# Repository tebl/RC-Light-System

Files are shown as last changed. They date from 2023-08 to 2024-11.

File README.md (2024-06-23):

# RC Light System
The *Arduino Starter Kit*, the official one with a bunch of parts and a book, was my first real introduction to working with electronics. Sure, I had put a new power plug on various things as a child of a different time that this one. What I hadn't done, was learn how to not blow things up when trying out new things. Arduino is pretty much perfect for that. Not in that you won't blow things up, it's more a case of blowing up really cheap parts and you rarely, if ever, actually set anything on fire. Working through it all, I wanted to create a project of my own - I would make a better light system for RCs.

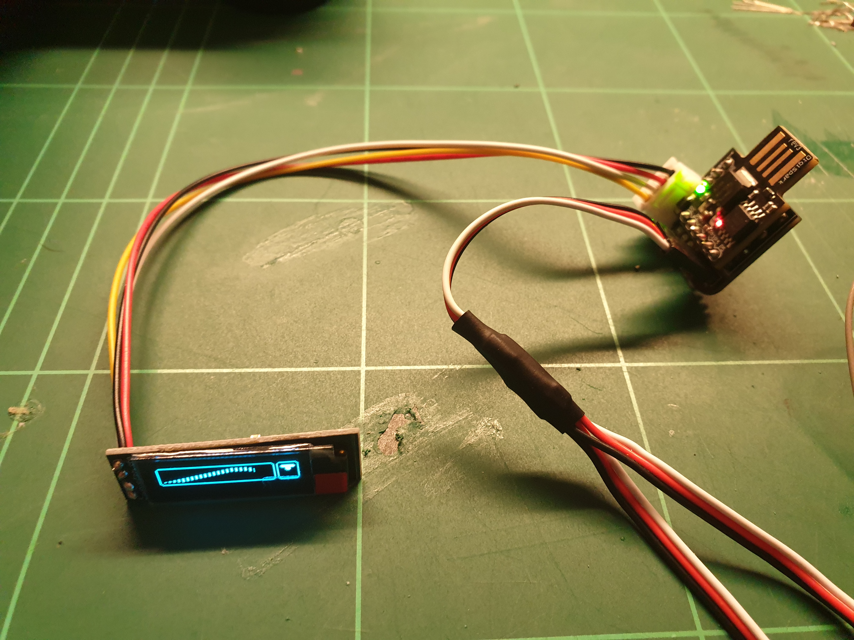
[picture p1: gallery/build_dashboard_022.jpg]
RC Dashboard


Yeah! Turns out that doing exactly that, requires understanding a lot more than simply plugging an LED into a breadboard and turning it on or off - there's logic levels, reading a PWM signal and then figuring out how to design your own PCBs. So I eventually put my parts in the infamous *"someday"* pile. A decade later, I've learned a few things and it was time to take something off that pile and try again! 

As I had a lot of fun doing it, I wanted to build a multitude of slightly different things around the same core theme - RCs, lighting and cool effects. For that reason I found it easier to organize them into their own sub-projects, so follow the links to the ones you are specifically interested in.

- [1> Projects](#1-projects)
  - [1.1> RC Light System](#11-rc-light-system)
  - [1.2> RC Exhaust](#12-rc-exhaust)
  - [1.3> RC Dashboard](#13-rc-dashboard)

# 1> Projects
For the technical details as well as information regarding the projects included in this specific github repository, consult the table below and follow along for the things that may interest you.  As each project will realistically end up being done in several different ways, they will each come with their own set of documentation as well as BOM-listings - these are organized by putting all that into the documentation for each module below it. Organized separately, you are also recommended to check out the [schematics](https://github.com/tebl/RC-Light-System/tree/main/documentation/schematic) for detailed information about how the electrical side of things work.

| Module | Description |
| --- | --- |
| [RC Light System](#11-rc-light-system)  | A functional light system for RCs. It's big, bulky and does mostly what I want it to do.
| [RC Exhaust](#12-rc-exhaust) | Controls an RGB LED mounted inside the exhaust pipe of an RC. On heavy throttle it starts glowing red, ease up on the trottle afterwards and you get flashing colours as it backfires.
| [RC Dashboard](#13-rc-dashboard) | Connected to the receiver, it shows a digital throttle gauge on a small OLED-screen.

## 1.1> RC Light System
This is the project I had originally intended to design, almost a decade earlier. A lighting system with some kind of recognizable intelligence to it. More specifically, something that wouldn't turn on the blinkers when turning the wheel. I could always just cut the wire, but I wanted it to work so that it felt more *scale* - turning on the blinker when cornering around a racetrack at subsonic speeds wasn't it. My second requirement was that it should be detachable by cable, mostly so that the electronics mounted on the chassis could be separated from those that are stuck to the body.

I can't physically work with small components, so as for any practical usage you will need a lot of space to install this - possibly a truck of some kind. Other than that, consider it *educational* material for anyone that wants to connect an Arduino to an RC-receiver.

| Module | Description |
| --- | --- |
| [RC Light System](https://github.com/tebl/RC-Light-System/tree/main/RC%20Light%20System)  | Main module for mounting on chassis, uses Arduino Pro Micro.
| [RC Light System Output](https://github.com/tebl/RC-Light-System/tree/main/RC%20Light%20System%20Output)  | Output-module for mounting on a body. Four sets of two LEDs can be combined to have two levels of brightness.
| [RC Light System Output Mini](https://github.com/tebl/RC-Light-System/tree/main/RC%20Light%20System%20Output%20Mini)  | Output-module for mounting on a body. Slightly smaller than the other one, with almost none of the interesting features apart from turning LEDs on and off.

## 1.2> RC Exhaust
Working with the [RC Light System](#11-rc-light-system), I came across small metal exhaust pipes for 1:10 RCs on AliExpress. Arriving in the mail a couple of months later I knew I had to install them in something, given that they were designed to fit an LED inside it - I wanted something more exciting than a basic effect. I wanted it to glow red on heavy throttle, backfire when easing up on the throttle and so on!

| Module | Description |
| --- | --- |
| [RC Exhaust Digispark](https://github.com/tebl/RC-Light-System/tree/main/RC%20Exhaust%20Digispark)  | Exhaust-module based around Digispark, with capability for RGB colour LED.

## 1.3> RC Dashboard
Tightly related to the [RC Exhaust](#12-rc-exhaust) in terms of implementation, mostly because I initially couldn't get it to work - so in the end I had to put a screen on one, all in order to figure out all the ways it had initially failed to work. That doesn't sound like a fun thing to build, but when doing it I had an idea - why not mount the screen inside the interior of an RC car? Cars generally have those, we call them *"dashboards"*.

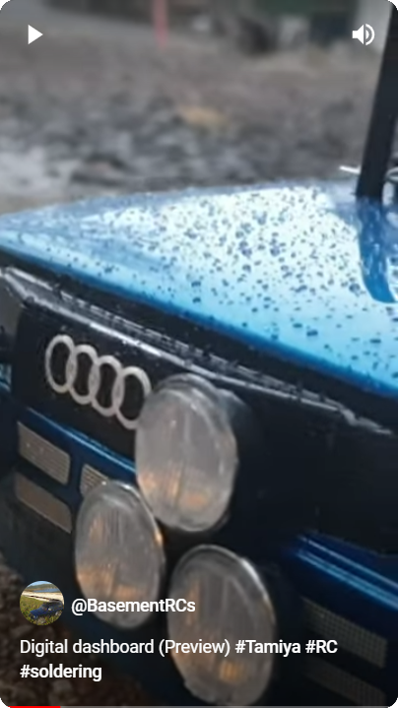
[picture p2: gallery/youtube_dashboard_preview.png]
YouTube image (https://youtube.com/shorts/HmBhJOPVMgE)


An electric RC doesn't exactly have a lot of telemetry that's available to plug into, but at least I can put a throttle gauge on it. Nowadays you'd probably want an analog one, but I designed this one to mimic the digital future that was on display in a limited selection of 80s and 90s cars - check out [The definitive collection of cool 1980s digital dashboards in Euro cars
](https://drivemag.com/red-calipers/the-definitive-collection-of-cool-1980s-digital-dashboards-in-euro-cars/) to see some examples of what I'm talking about here.

| Module | Description |
| --- | --- |
| [RC Dashboard Digispark](https://github.com/tebl/RC-Light-System/tree/main/RC%20Dashboard%20Digispark)  | Dashboard-module based around Digispark.

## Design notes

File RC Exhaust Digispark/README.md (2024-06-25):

# RC Exhaust (Digispark)
Working with the RC Light System, I came across a small metal exhaust pipe for 1:10 RCs on AliExpress. Arriving in the mail a couple of months later, I knew I had to install them in something. Careful measuring revealed that they were designed to fit an LED inside it, and later versions that I picked up even came with one included. I did however want something that was a little more dynamic than a static LED could provide and while I could have gone with the 555, I went the full route of the Attiny85. Granted, I did have some Digispark modules that I'd never found a use for. Until now.

The plan was to have the exhaust pipe glow red on heavy throttle, then backfire when easing up on the throttle. It'll throw in some regular sparks here and there to make it come alive a bit more than that, but the code is included here if you want something else.

- [1> Building the device](#1-building-the-device)
- [2> Schematic](#2-schematic)
- [3> BOM](#3-bom)

# 1> Building the device
Building the device should be a straight-forward affair, you just solder the meager selection of components into place. Pay attention to keep the alignment of the parts somewhat straight, then you should be good. This documentation was written with a board that looks like the following in mind, but note that the github-repository may contain changes that have yet to be tested (therefore, it is recommend that PCBs are ordered using PCBWay links listed in the BOM).

The Attiny85 is a 5v chip, and we're connecting it to a 6v source due to it living inside an RC. Normally that would toast it as we're working outside the acceptable ranges, but we're using a diode with a voltage drop that's up to 0.7v - bringing us withing the tolerances of the chip. As for installation, just match the silver stripe on the component to the stripe part on the board and you're good to go.

Resistors should be added, but you can *probably* skip R4 and R5 - those form a voltage divider in case the receiver is sending out a signal that's above 3.3v. I've not encountered any of those, but then again - I don't have RC equipment older than a decade or so. Link the corresponding *NO_VOL_DIV* pads on the back of it if you've skipped them.

The three at the bottom are for the LEDs, here you may need to match the datasheet for your specific LED, per colour, in order to arrive at a suitable resistor value. Consult a [LED Series Resistor Calculator](https://www.digikey.com/en/resources/conversion-calculators/conversion-calculator-led-series-resistor) if you need to (set supply voltage to 5.3v, fill in 10mA current for blue/green and 15mA for red).

The Digispark itself is then soldered on top, with straight pin headers between the two. It doesn't matter if you used the Digispark shaped like a "USB-key", or if it has a Micro-USB socket on it - they fit just the same. Personally I prefer the former as it is easier to wipe off compared to pulling debris out of a socket.

The LED must be attached to the board using a removable lead, which is why I'm using JST XH plugs on mine. When wiring for an RGB LED it must be a common anode variety, but you can use a normal LED as well - just wire it up to the board as *RED*. If you don't care about being able to reprogram the board later, you can just solder the wires directly. When soldering onto the LED legs, I recommend using heat shrink tubing to avoid any accidents. An easier alternative is to use a pre-wired red LED and just connect up those two leads, but won't look as fancy.

The left hand side is where you connect up the wire coming from the ESC, there are two here - mainly so that you could use it as a Y-lead without requiring any additional cables. Solder wires, or install pin headers depending on what you prefer.

# 2> Schematic
The supplied KiCad files should be sufficient as both a schematic and as a  starting point for ordering PCBs (basically you could just zip the contents of the export folder and upload that on a fabrication site), the schematic is also available in [PDF-format](https://github.com/tebl/RC-Light-System/tree/main/documentation/schematic) and this is what you'll need to print and work your way through when things fail to work as expected.

# 3> BOM
Most parts should be easy to get a hold of from your favourite local electronic component shop, but given that I don't have access to such shops where I live so everything was based on whatever I could get cheapest from eBay/AliExpress (free shipping, but plan on waiting 3-4 weeks for delivery). As I expect that most will build this adapter solely for MIDI-output, the values required for the MIDI input have been listed in parenthesis.

| Reference | Item | Count | Order  |
| ---| --- | ----- | --- |
| Faceplate PCB  | Fabricate using Gerber files | 1 | PCBWay
| A1 | Digispark-module (with pin-headers) | 1 |
| D1 * | 4-pin JST-XH socket | 1 |
| | 5mm LED, common-anode variety to 4-pin JST-XH plug | 1 |
| D2 | 1N4001 diode (DO-41) | 1 |
| J5,J6 | Straight pin-headers, alternatively wire a Y-splitter | 1 |
| R1 | 200 ohm resistor | 1 |
| R2,R3 | 270 ohm resistor | 2 |
| R4 | 10k ohm resistor | (1)|
| R5 | 20k ohm resistor | (1)|

*) You can come up with something else here, but JST-XH is what I recommend. They're keyed and locking so they won't come off very easily. For the LED, I recommend buying pre-wired 4-pin JST-XH leads with plugs already on it - you'll need to solder it to the individual LED legs though (use heat shrink tubing).

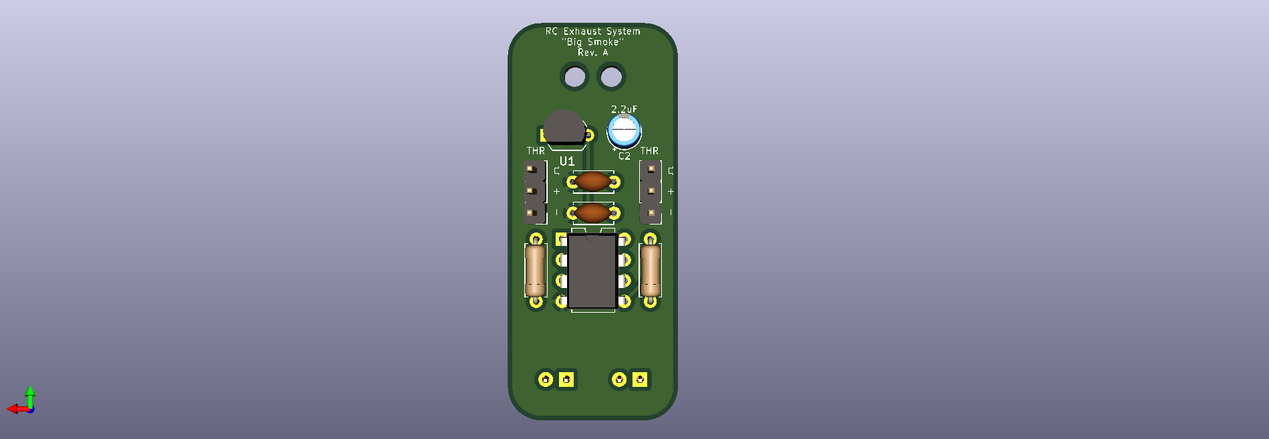
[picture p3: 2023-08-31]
gallery/RC Exhaust System (Top).png

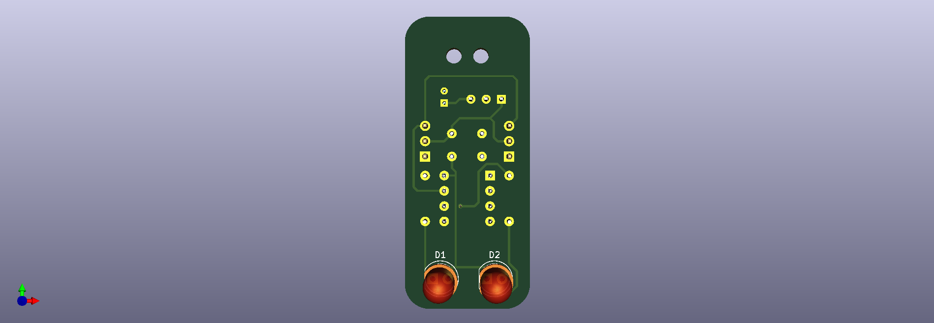
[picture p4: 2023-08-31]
gallery/RC Exhaust System (Bottom).png

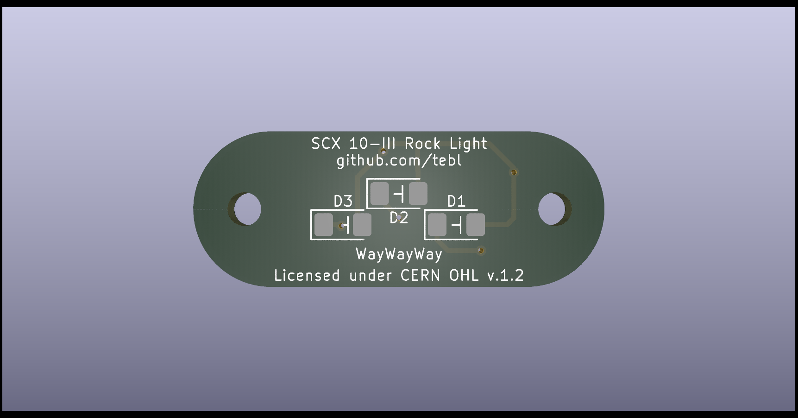
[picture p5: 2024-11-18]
gallery/RC SCX10.3 Rock Light (Bottom).png

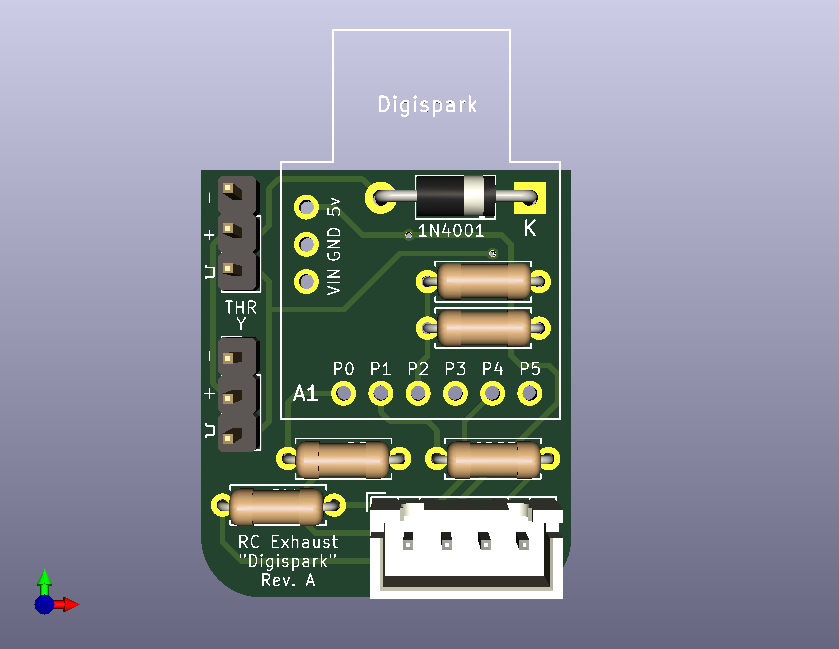
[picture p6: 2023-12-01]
gallery/RC Exhaust Digispark.png

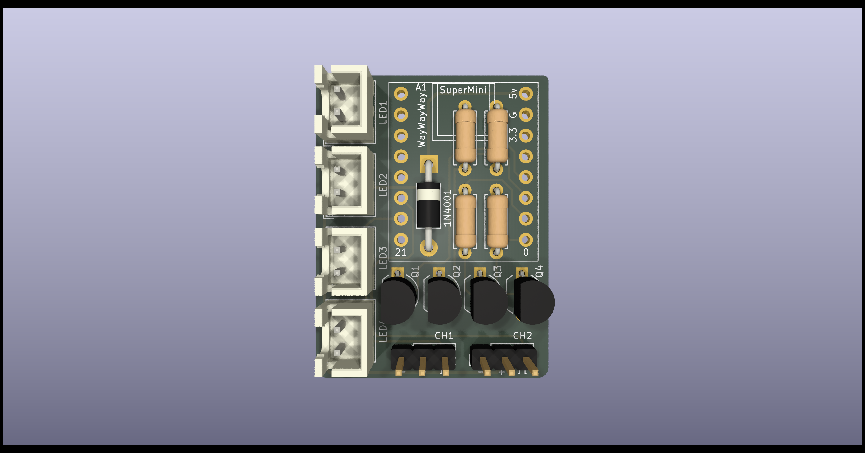
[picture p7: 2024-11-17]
gallery/RC SCX10.3 Rock Control.png

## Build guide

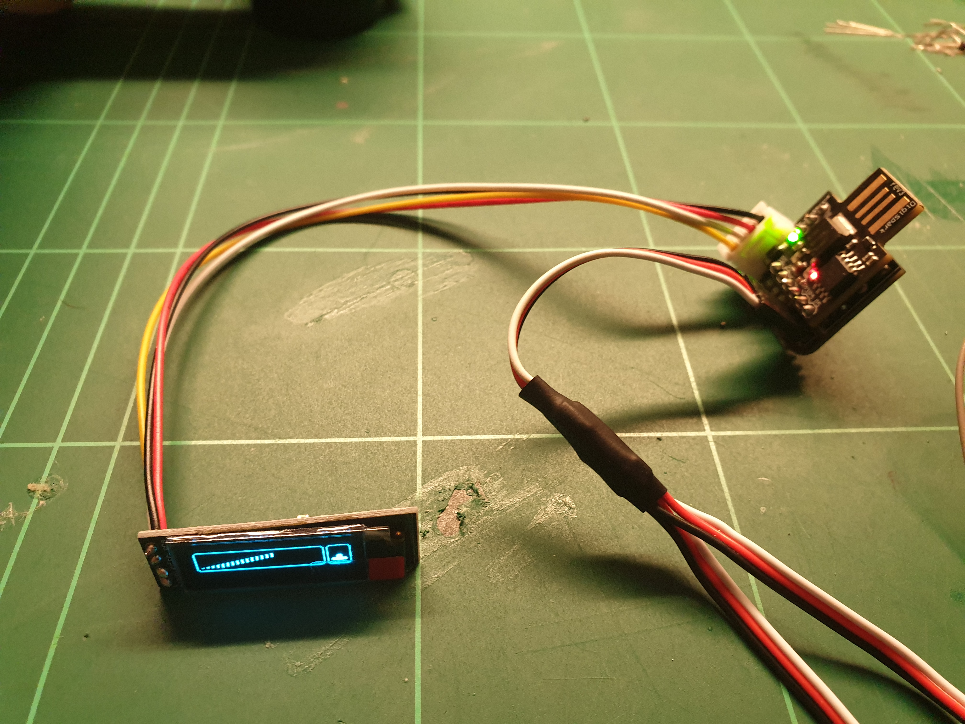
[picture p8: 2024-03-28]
gallery/build_dashboard_023.jpg

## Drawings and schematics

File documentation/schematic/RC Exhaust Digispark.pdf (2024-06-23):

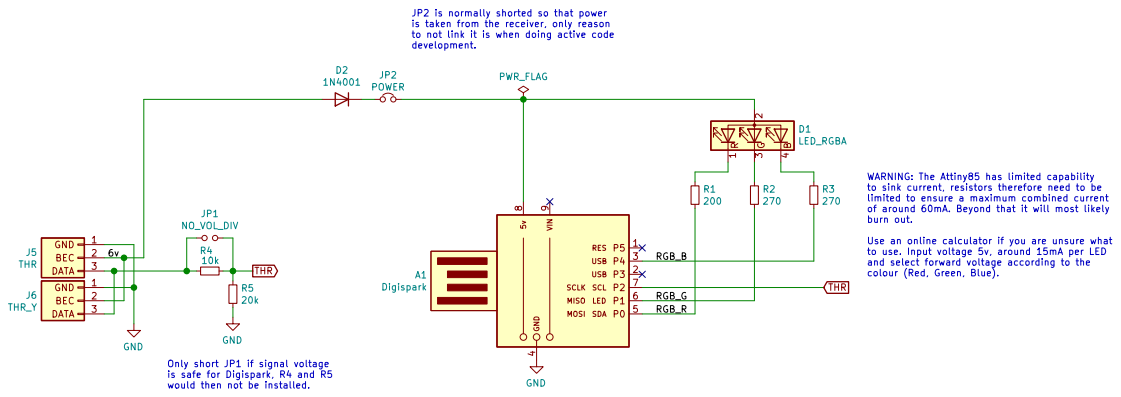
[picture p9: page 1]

JP2 is normally shorted so that power
is taken from the receiver, only reason
to not link it is when doing active code
development.

to sink current, resistors therefore need to be
limited to ensure a maximum combined current of around 60mA. Beyond that it will most likely burn out. Use an online calculator if you are unsure what

SCLK SCL SDA USB USB VIN

RGB_B Only short JP1 if signal voltage

to use. Input voltage 5v, around 15mA per LED
and select forward voltage according to the
colour (Red, Green, Blue).

Found some exhaust tubes for a 1:10 model on AliExpress, let's add some glow effects to BEC

File: RC Exhaust Digispark.sch Sheet: /
Id: 1/1 Title: RC Exhaust Digispark

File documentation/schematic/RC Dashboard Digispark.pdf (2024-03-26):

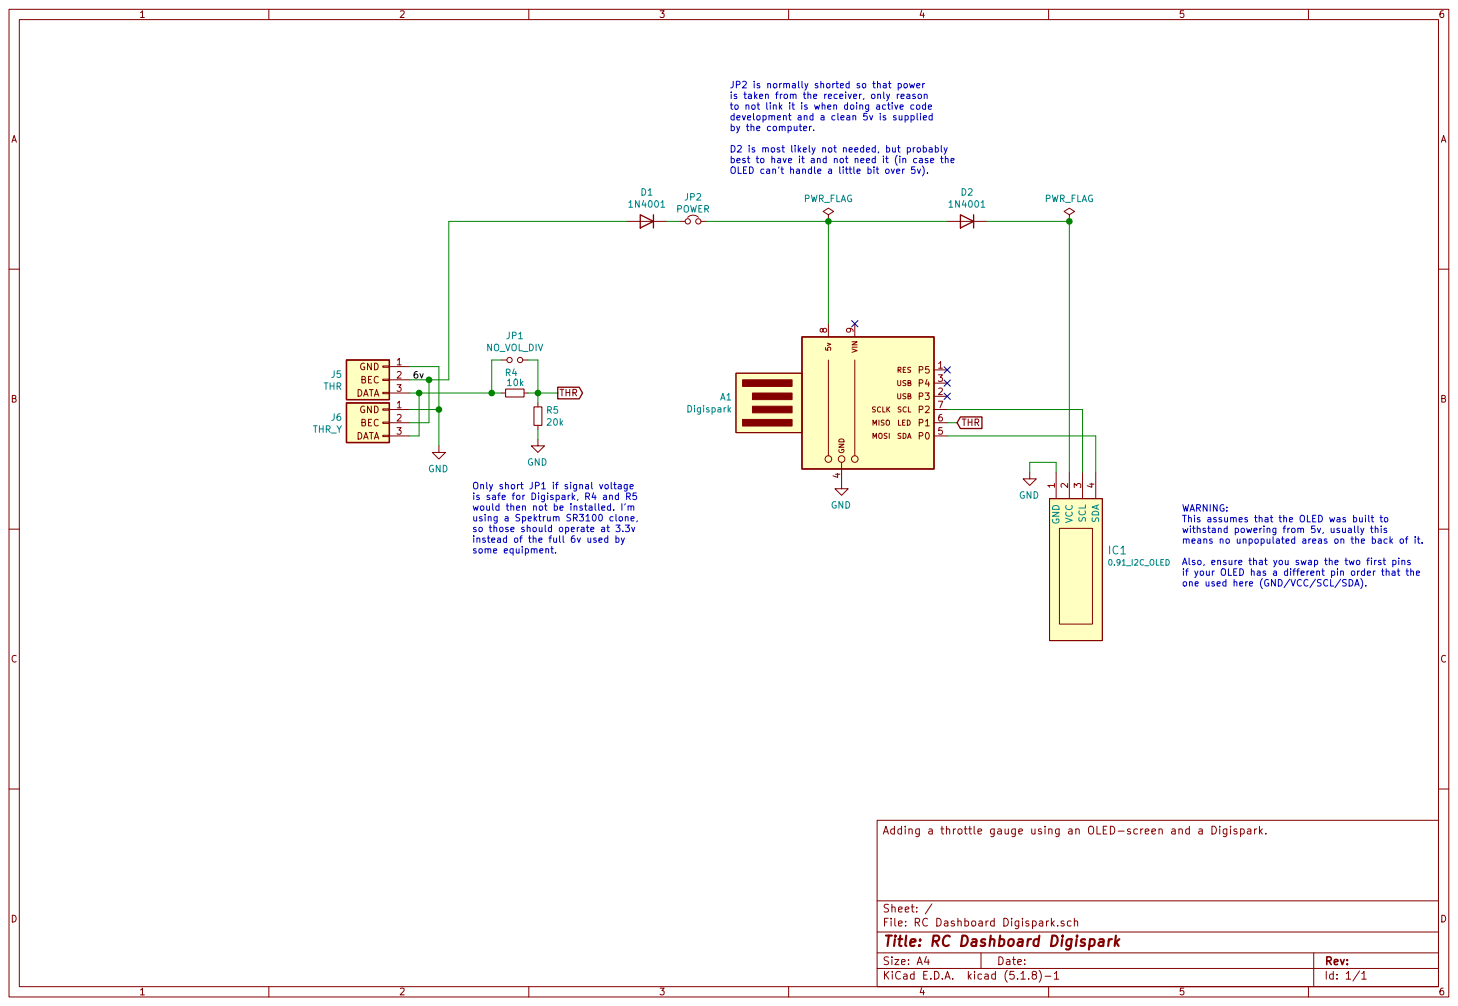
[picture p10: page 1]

JP2 is normally shorted so that power
is taken from the receiver, only reason
to not link it is when doing active code
development and a clean 5v is supplied
by the computer.

D2 is most likely not needed, but probably
best to have it and not need it (in case the

SCLK SCL SDA USB USB VIN

File: RC Dashboard Digispark.sch Sheet: / Adding a throttle gauge using an OLED-screen and a Digispark. BEC

Only short JP1 if signal voltage
is safe for Digispark, R4 and R5 would then not be installed. I'm

using a Spektrum SR3100 clone,
so those should operate at 3.3v
instead of the full 6v used by
some equipment.

means no unpopulated areas on the back of it.

Also, ensure that you swap the two first pins
if your OLED has a different pin order that the
one used here (GND/VCC/SCL/SDA).

Id: 1/1 Title: RC Dashboard Digispark

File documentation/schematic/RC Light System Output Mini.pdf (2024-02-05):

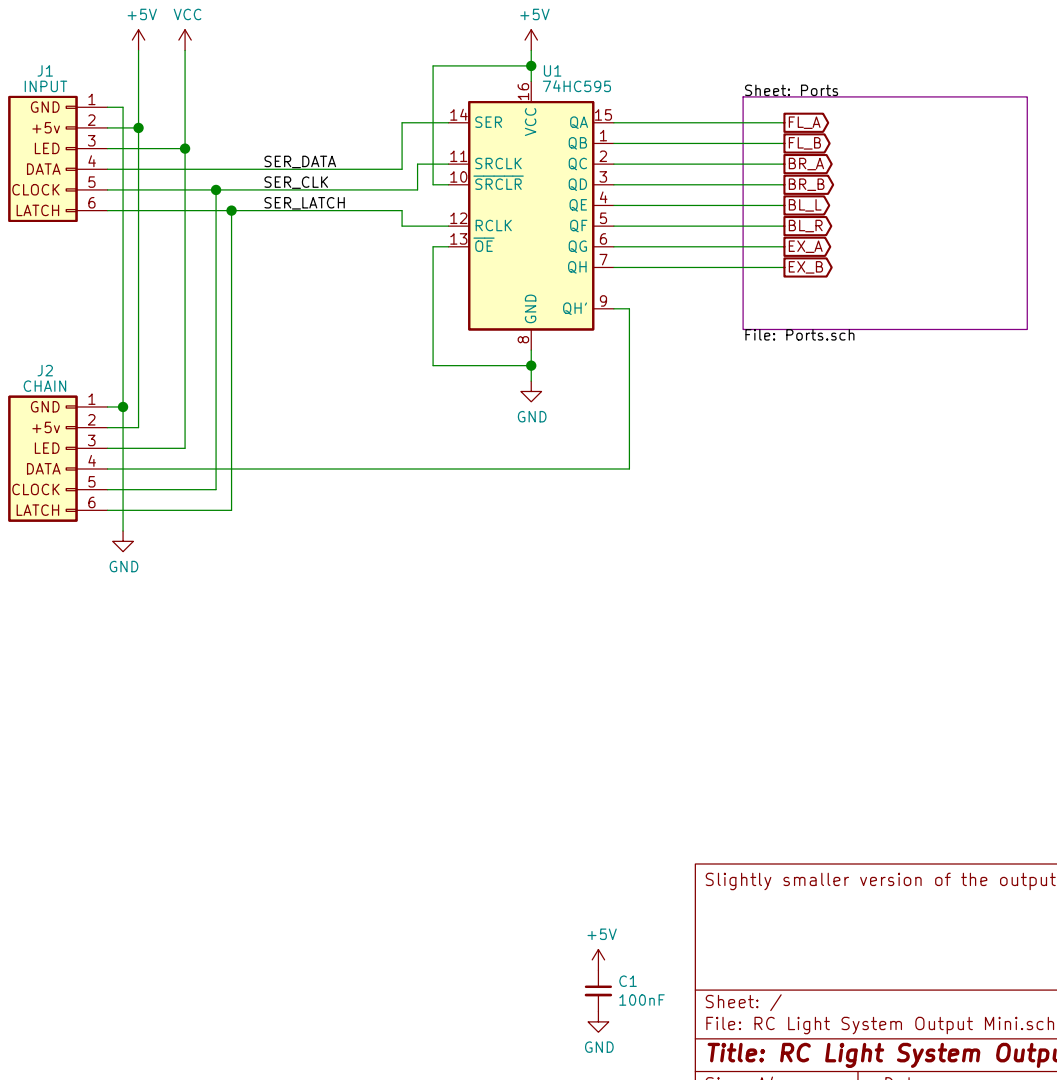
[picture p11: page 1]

Sheet: Ports File: Ports.sch +5V C1

5 | SER_CLK
6 | | SER_LATCH

File: RC Light System Output Mini.sch Sheet: / Slightly smaller version of the output module, gone are most of the interesting features.

Id: 1/2 Title: RC Light System Output (Mini)

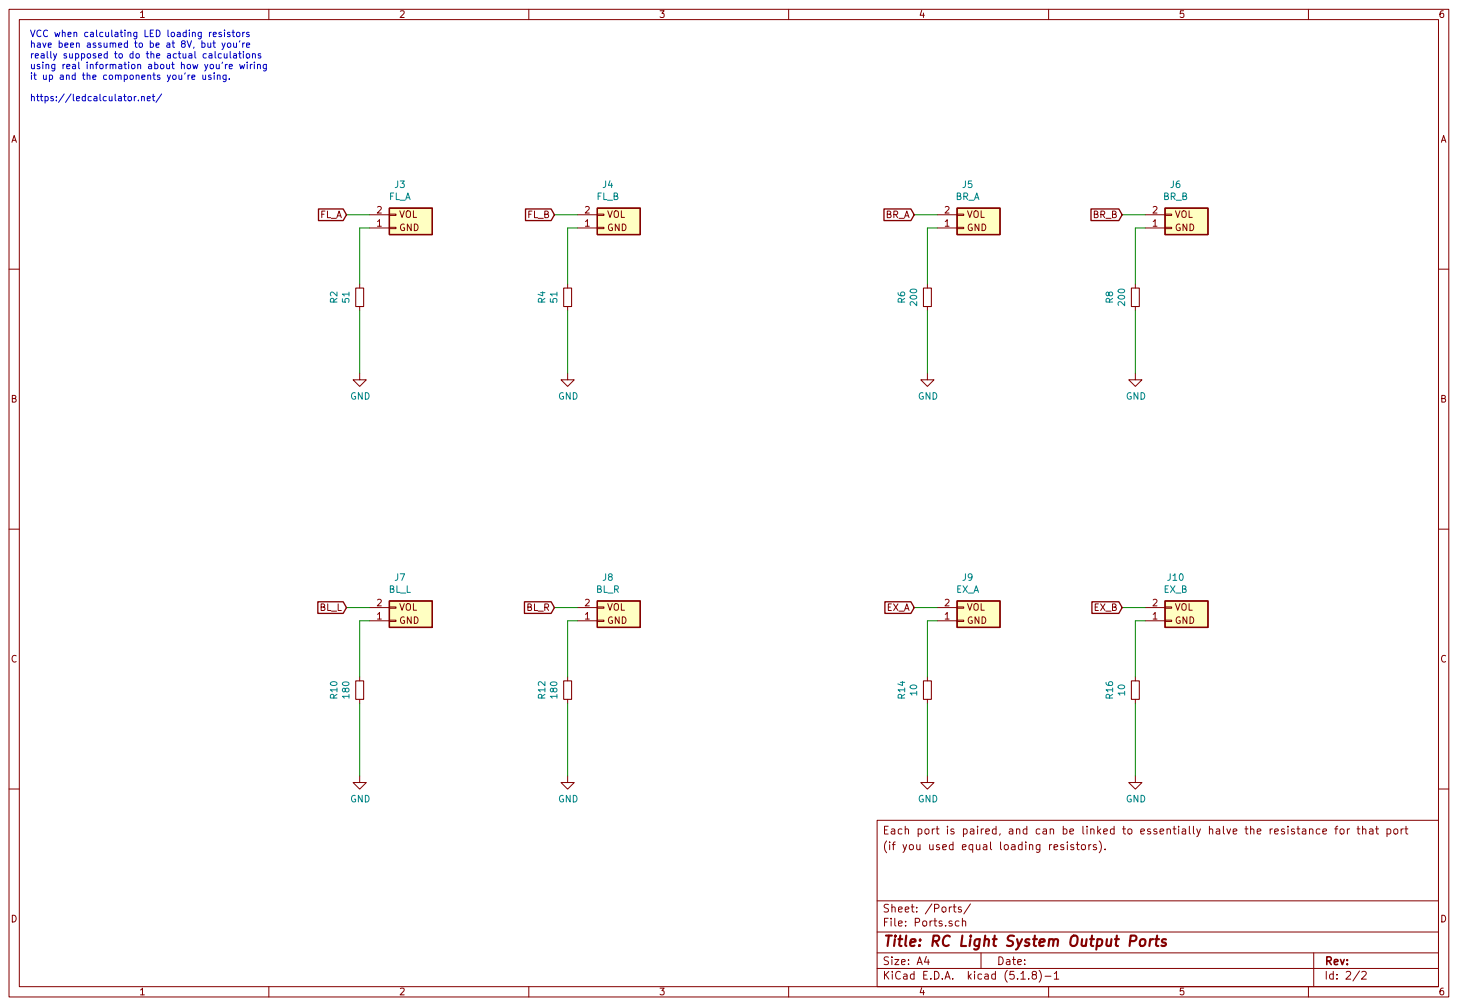
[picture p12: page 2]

VCC when calculating LED loading resistors
have been assumed to be at 8V, but you're
really supposed to do the actual calculations
using real information about how you're wiring
it up and the components you're using.

File: Ports.sch Sheet: /Ports/ (if you used equal loading resistors).

Id: 2/2 Title: RC Light System Output Ports

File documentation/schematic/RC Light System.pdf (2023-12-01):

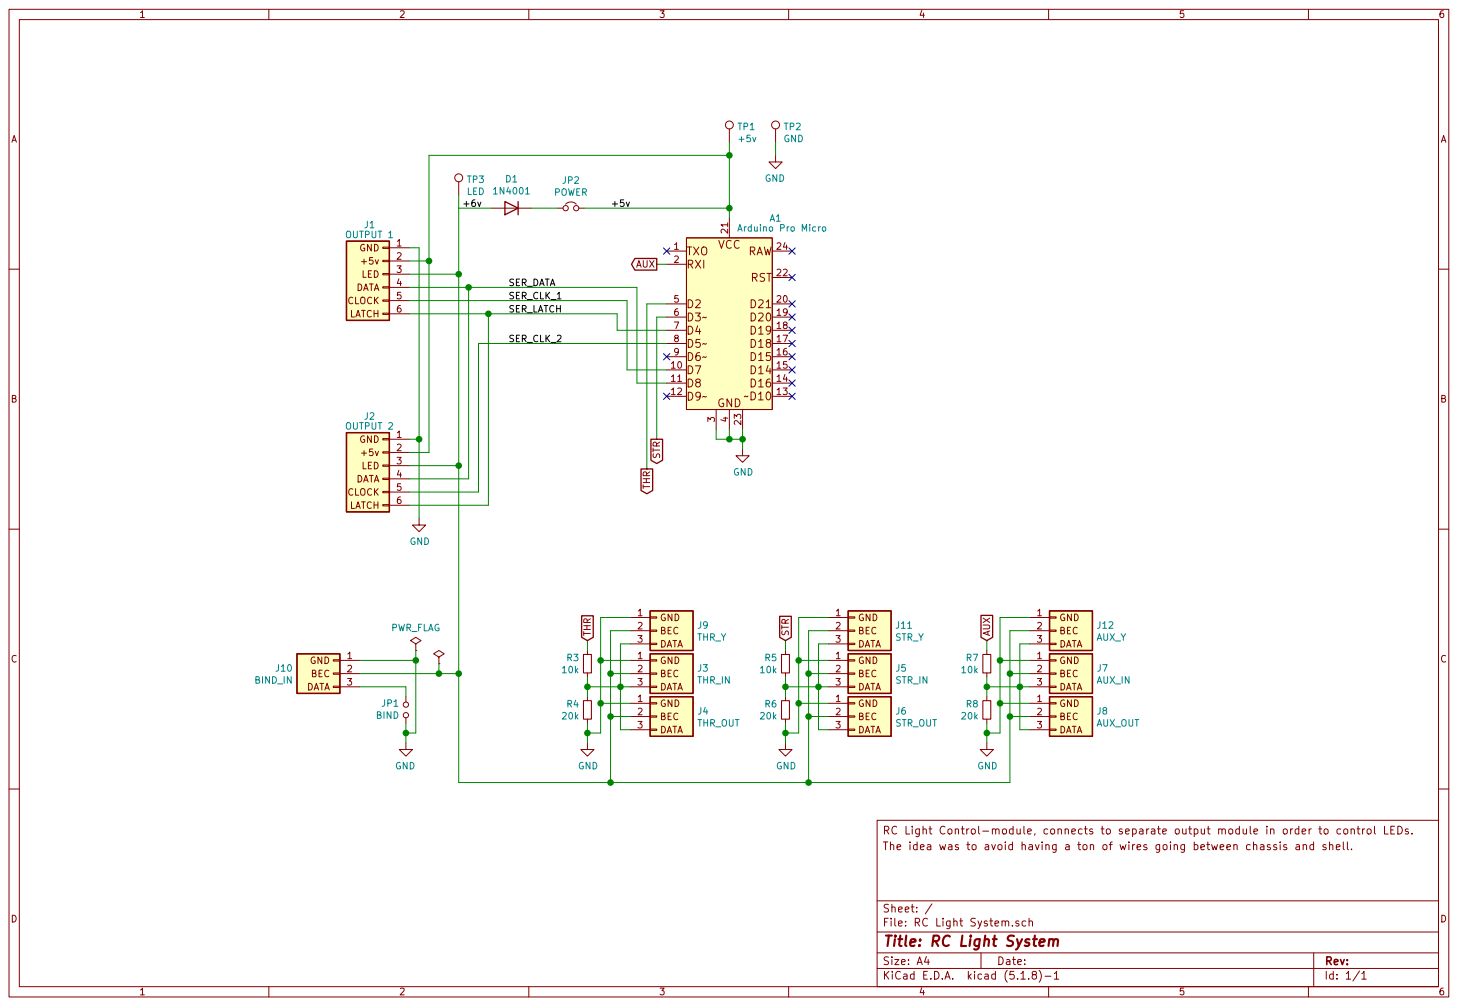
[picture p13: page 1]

10
11

RC Light Control-module, connects to separate output module in order to control LEDs.
File: RC Light System.sch Sheet: / The idea was to avoid having a ton of wires going between chassis and shell.

Id: 1/1 Title: RC Light System

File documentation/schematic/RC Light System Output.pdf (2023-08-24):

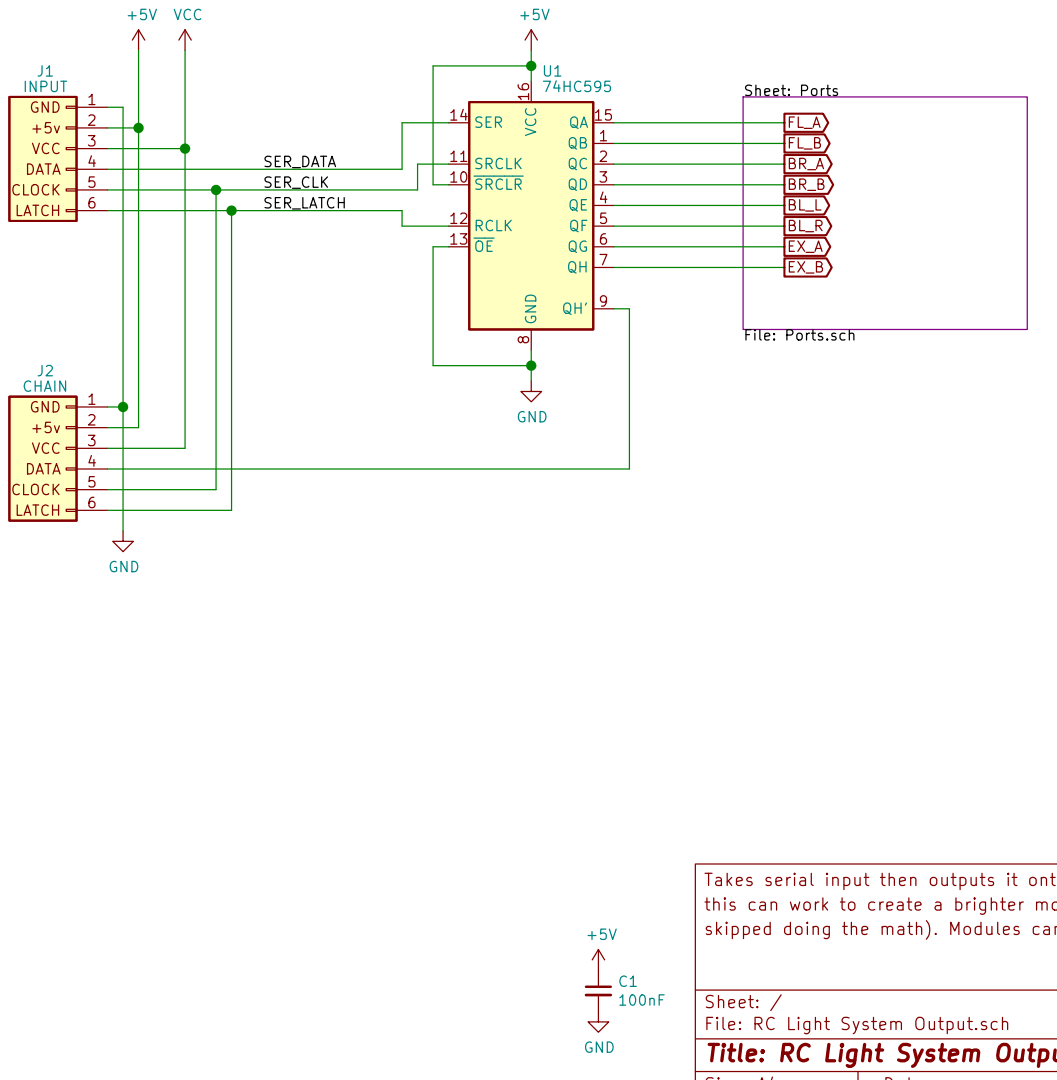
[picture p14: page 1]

Sheet: Ports File: Ports.sch +5V C1

5 | SER_CLK
6 | | SER_LATCH

Takes serial input then outputs it onto LED "ports". Each port is paired and can be linked,
this can work to create a brighter mode for the LEDs connected (or burn something if you
File: RC Light System Output.sch Sheet: / skipped doing the math). Modules can be chained for more outputs.

Id: 1/2 Title: RC Light System Output

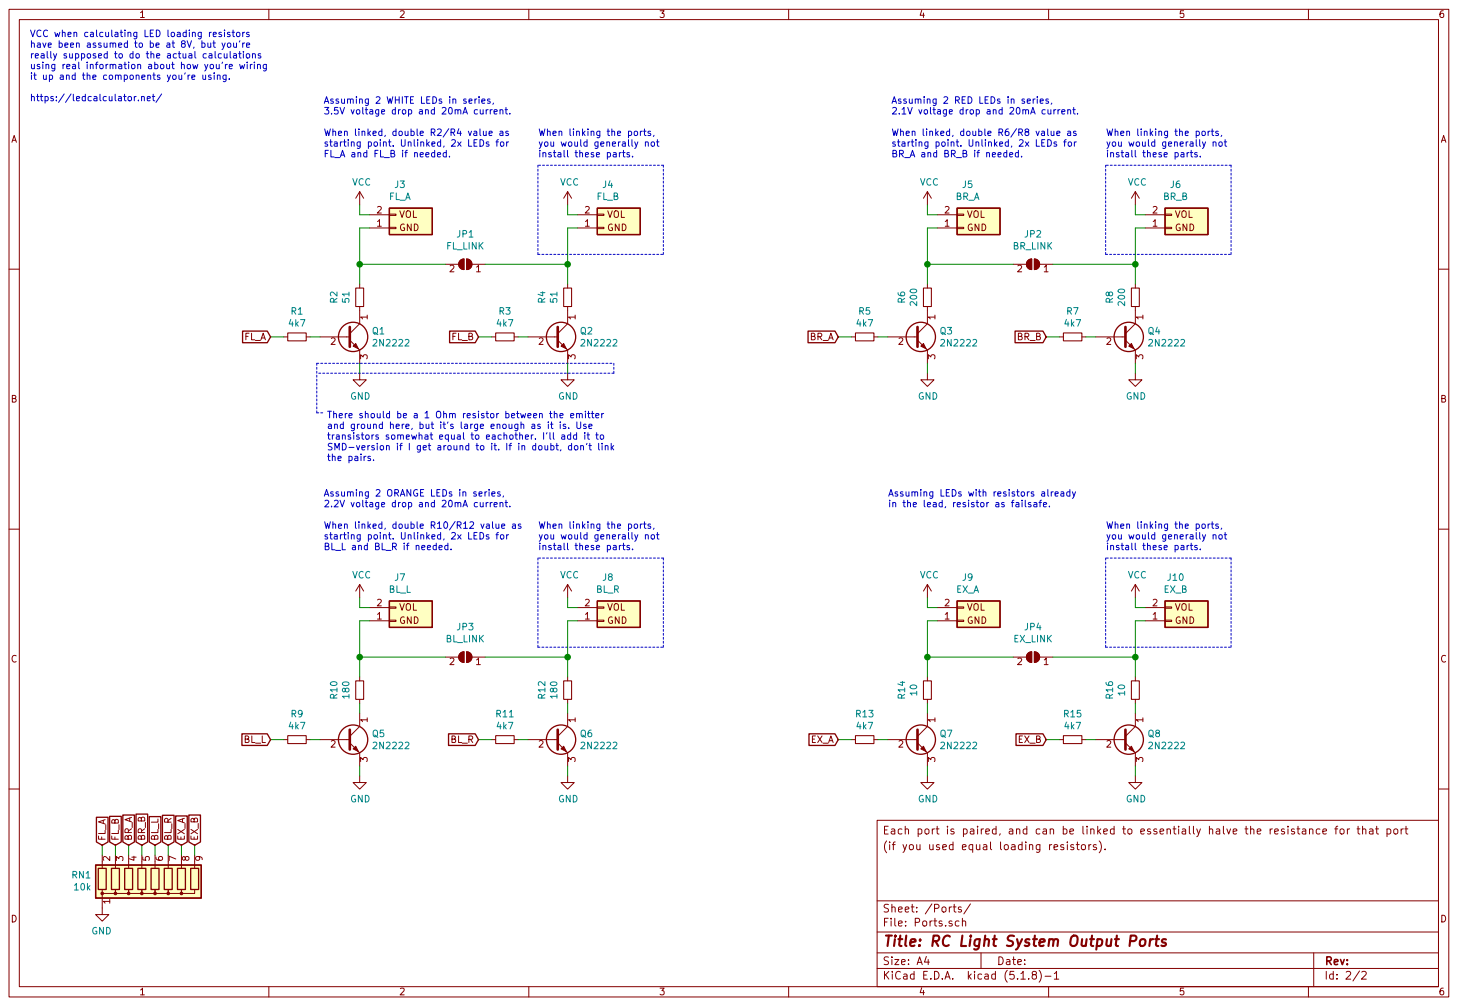
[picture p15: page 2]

VCC when calculating LED loading resistors
have been assumed to be at 8V, but you're
really supposed to do the actual calculations
using real information about how you're wiring
it up and the components you're using.

starting point. Unlinked, 2x LEDs for FL_A and FL_B if needed. Assuming 2 WHITE LEDs in series,
3.5V voltage drop and 20mA current.
VCC R16 10 R6 200 VCC GND

starting point. Unlinked, 2x LEDs for BR_A and BR_B if needed. Assuming 2 RED LEDs in series,
2.1V voltage drop and 20mA current.

install these parts. When linked, double R2/R4 value as

in the lead, resistor as failsafe. When linking the ports,
you would generally not

When linking the ports,

install these parts. When linked, double R10/R12 value as
J7 BL_LVOL GND 1

There should be a 1 Ohm resistor between the emitter and ground here, but it's large enough as it is. Use

transistors somewhat equal to eachother. I'll add it to
SMD-version if I get around to it. If in doubt, don't link
the pairs.

starting point. Unlinked, 2x LEDs for BL_L and BL_R if needed. Assuming 2 ORANGE LEDs in series,
2.2V voltage drop and 20mA current.

Assuming LEDs with resistors already

VCC R12 180

install these parts.

Each port is paired, and can be linked to essentially halve the resistance for that port
File: Ports.sch Sheet: /Ports/ (if you used equal loading resistors).

Id: 2/2 Title: RC Light System Output Ports

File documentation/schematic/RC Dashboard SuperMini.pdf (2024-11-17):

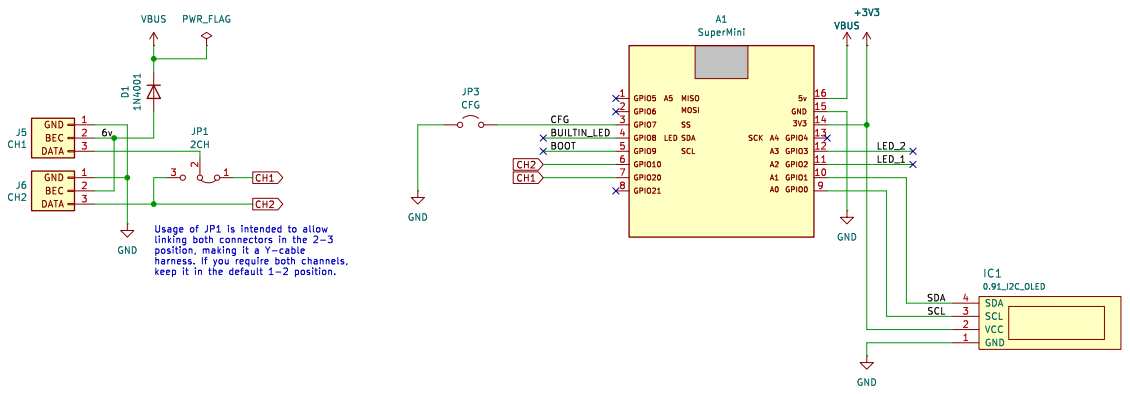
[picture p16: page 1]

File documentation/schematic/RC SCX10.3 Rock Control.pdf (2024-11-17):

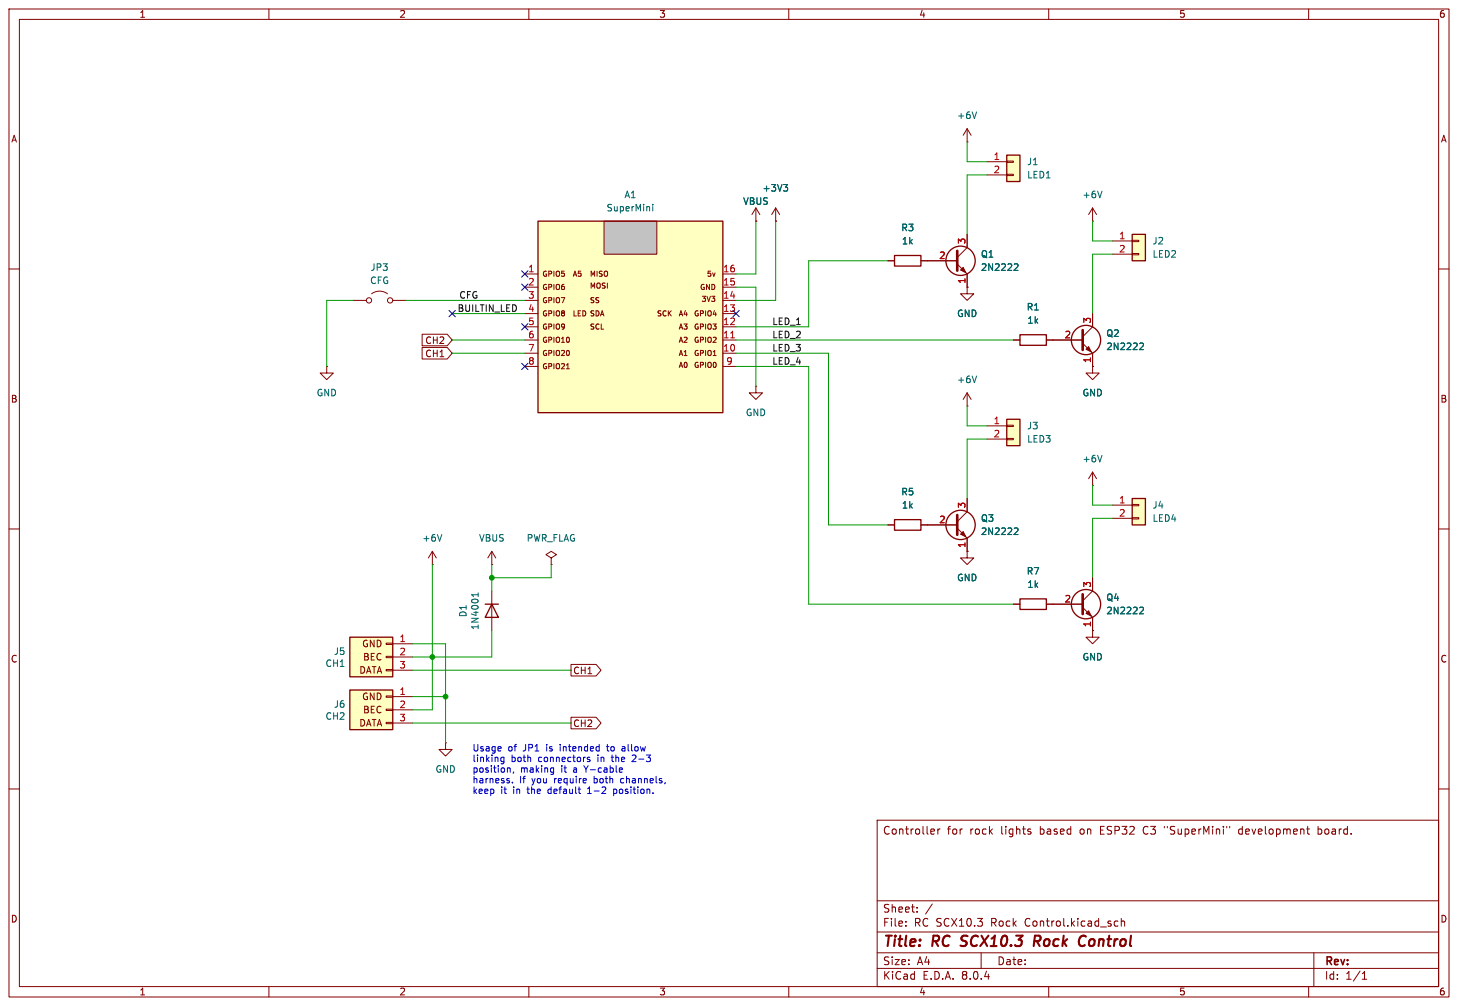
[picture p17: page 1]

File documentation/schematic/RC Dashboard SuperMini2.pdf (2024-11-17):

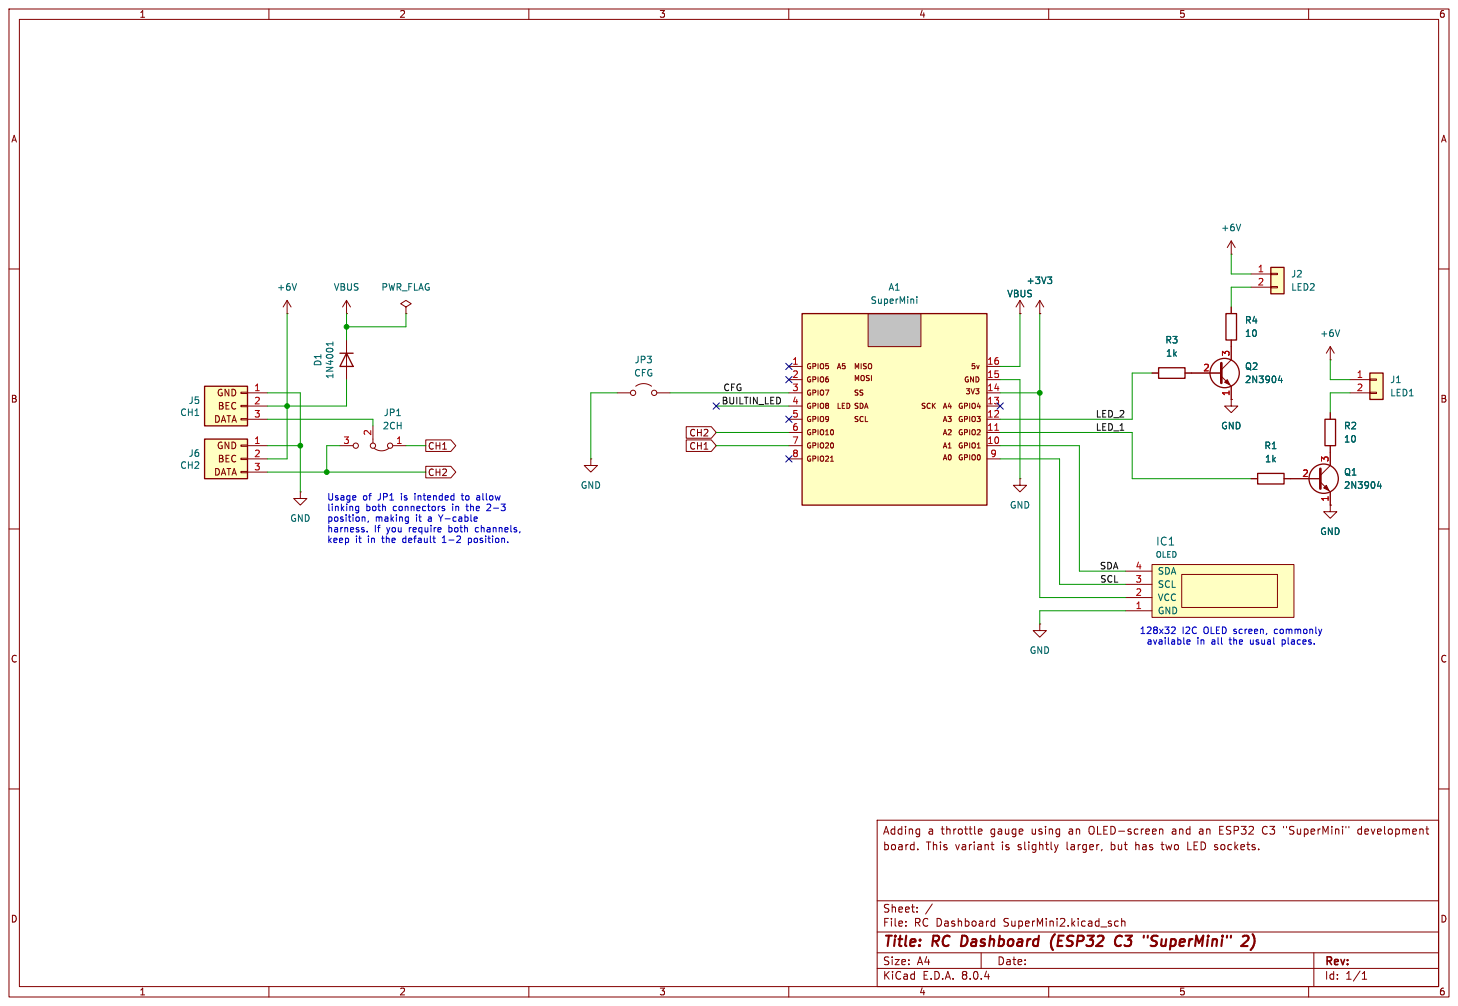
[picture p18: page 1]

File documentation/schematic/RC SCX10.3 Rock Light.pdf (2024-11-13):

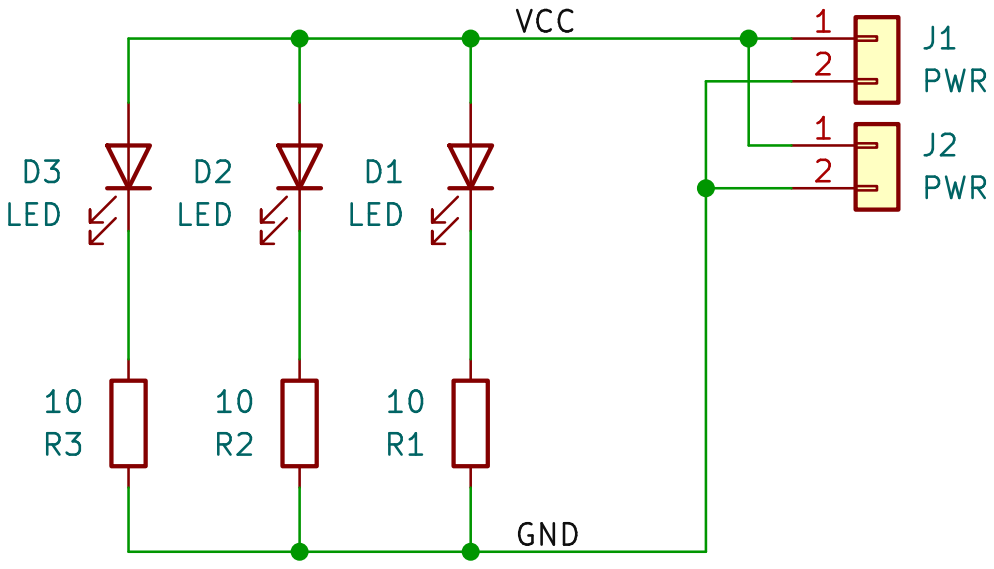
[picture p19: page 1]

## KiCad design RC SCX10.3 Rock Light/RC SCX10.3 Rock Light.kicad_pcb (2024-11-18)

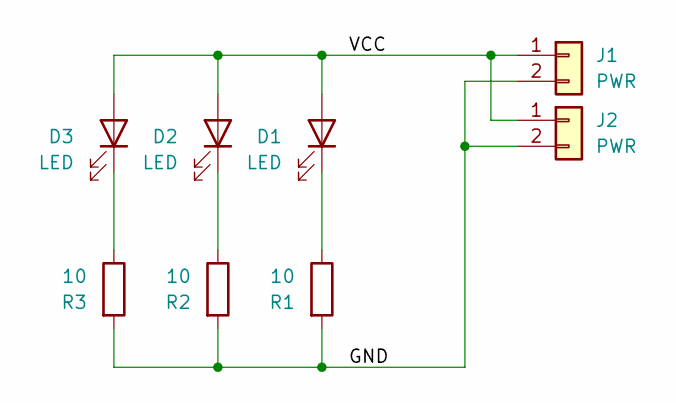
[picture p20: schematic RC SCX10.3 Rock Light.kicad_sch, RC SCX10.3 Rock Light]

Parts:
D1, D2, D3: LED; LED_1206_3216Metric_Pad1.42x1.75mm_HandSolder
J1, J2: PWR; edge_pins_1x02
R1, R2, R3: 10; R_1206_3216Metric_Pad1.30x1.75mm_HandSolder

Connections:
/GND: J1.2, J2.2, R1.2, R2.2, R3.2
/VCC: D1.2 (A), D2.2 (A), D3.2 (A), J1.1, J2.1
unnamed: D1.1 (K), R1.1
unnamed: D2.1 (K), R2.1
unnamed: D3.1 (K), R3.1

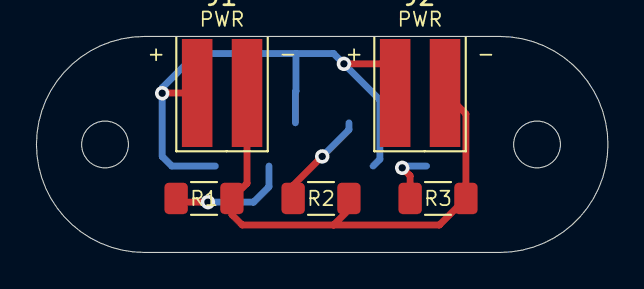
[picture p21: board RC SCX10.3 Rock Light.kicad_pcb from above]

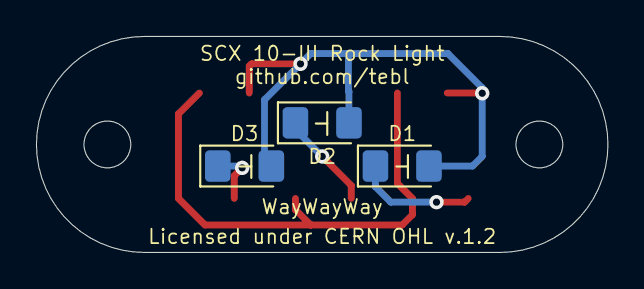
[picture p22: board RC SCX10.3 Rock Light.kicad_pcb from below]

Board: 2 copper layers, 31.8 x 12.0 mm, 8 parts (3 on the bottom side), 5 nets.

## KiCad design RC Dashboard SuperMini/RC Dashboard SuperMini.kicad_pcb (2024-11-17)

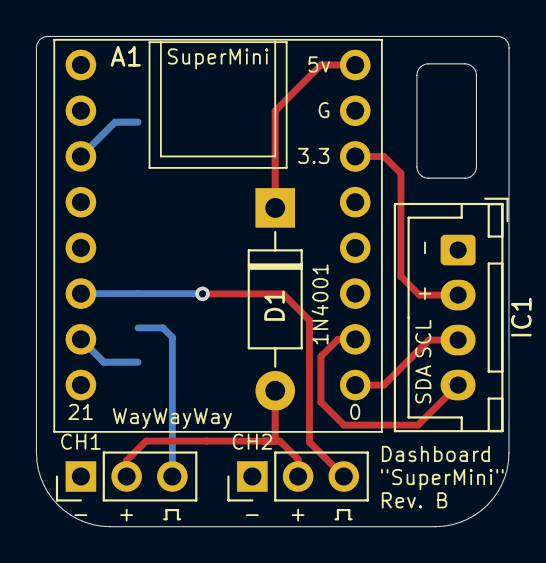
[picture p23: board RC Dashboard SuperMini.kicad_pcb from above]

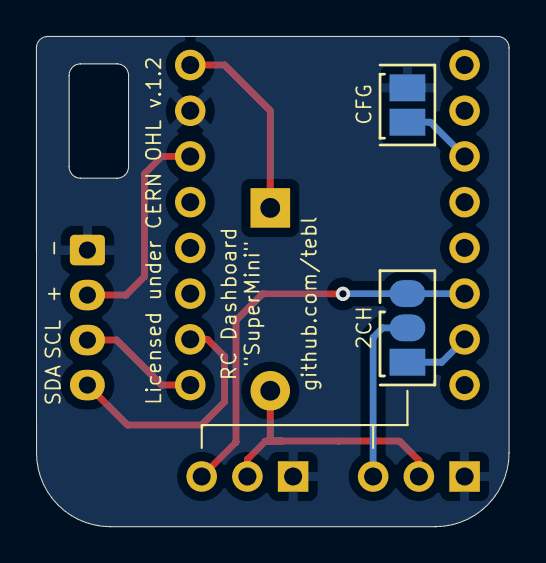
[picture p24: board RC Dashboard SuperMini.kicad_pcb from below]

Board: 2 copper layers, 26.3 x 27.2 mm, 7 parts (2 on the bottom side), 10 nets.

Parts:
A1: SuperMini; SuperMini_ESP32_C3
D1: 1N4001; D_DO-41_SOD81_P10.16mm_Horizontal
IC1: 0.91_I2C_OLED; JST_XH_B4B-XH-A_1x04_P2.50mm_Vertical
J5: CH1; PinHeader_1x03_P2.54mm_Vertical
J6: CH2; PinHeader_1x03_P2.54mm_Vertical
JP1: 2CH; select2
JP3: CFG; bridge

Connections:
+3V3: A1.14 (3V3), IC1.2 (VCC)
/6v: D1.2 (A), J5.2 (BEC), J6.2 (BEC)
/CFG_2: A1.3 (GPIO7), JP3.2 (B)
/SCL: A1.9 (GPIO0), IC1.3 (SCL)
/SDA: A1.10 (GPIO1), IC1.4 (SDA)
CH1: A1.7 (GPIO20), JP1.1 (A)
CH2: A1.6 (GPIO10), J6.3 (VCC), JP1.3 (B)
GND: A1.15 (GND), IC1.1 (GND), J5.1 (GND), J6.1 (GND), JP3.1 (A)
unnamed: J5.3 (VCC), JP1.2 (C)
VBUS: A1.16 (5v), D1.1 (K)

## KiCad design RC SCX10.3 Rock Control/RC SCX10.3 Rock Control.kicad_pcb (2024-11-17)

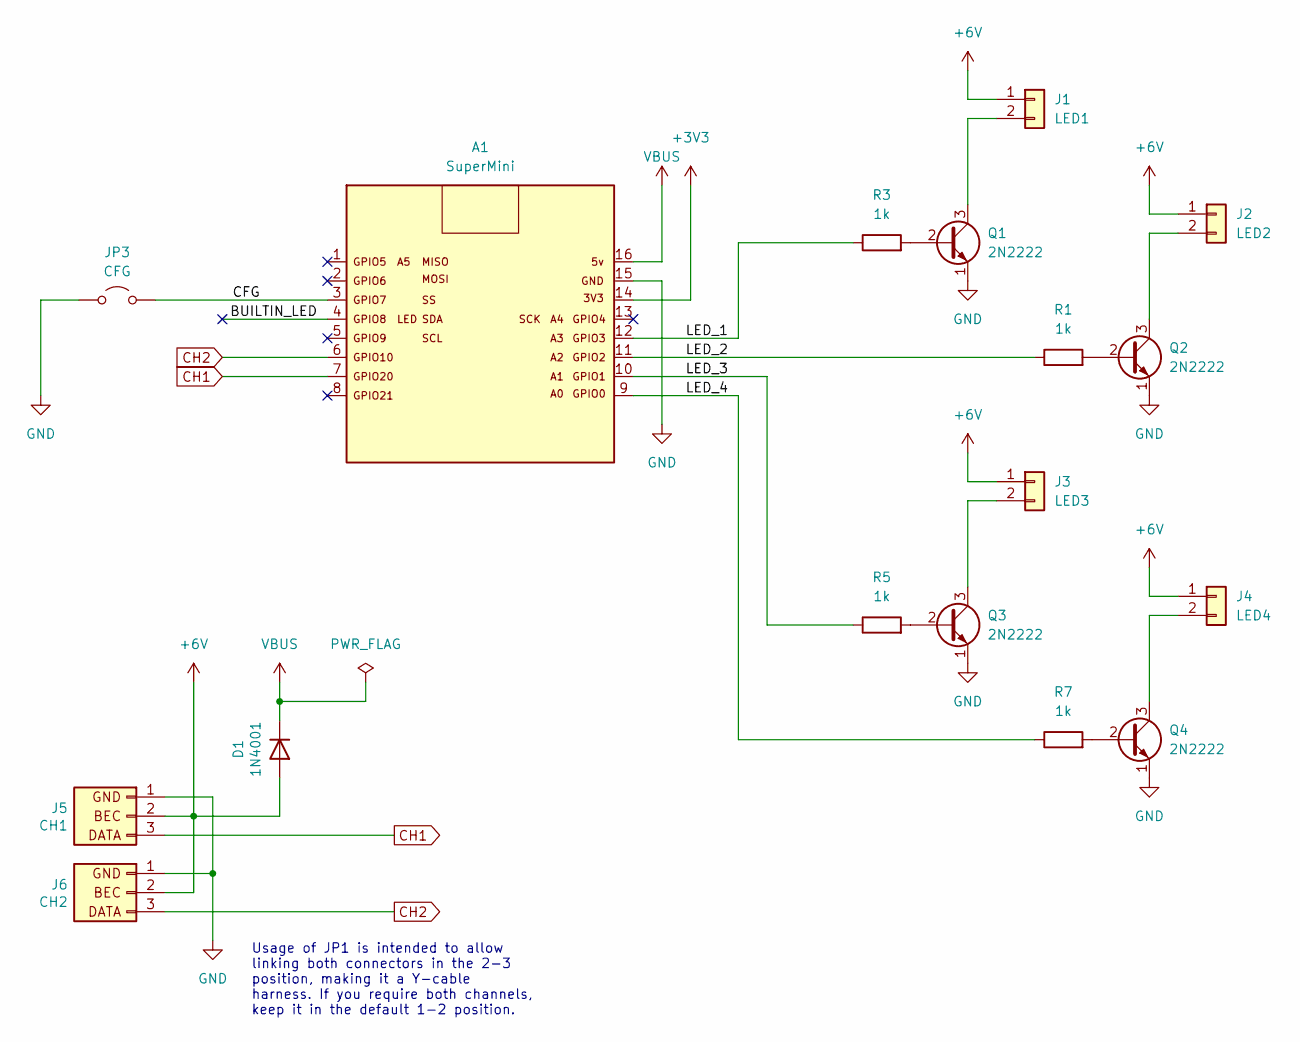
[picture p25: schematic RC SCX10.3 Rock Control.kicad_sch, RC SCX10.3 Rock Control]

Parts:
A1: SuperMini; SuperMini_ESP32_C3
D1: 1N4001; D_DO-41_SOD81_P10.16mm_Horizontal
J1: LED1; JST_XH_B2B-XH-A_1x02_P2.50mm_Vertical
J2: LED2; JST_XH_B2B-XH-A_1x02_P2.50mm_Vertical
J3: LED3; JST_XH_B2B-XH-A_1x02_P2.50mm_Vertical
J4: LED4; JST_XH_B2B-XH-A_1x02_P2.50mm_Vertical
J5: CH1; PinHeader_1x03_P2.54mm_Vertical
J6: CH2; PinHeader_1x03_P2.54mm_Vertical
JP3: CFG; bridge
Q1, Q2, Q3, Q4: 2N2222; TO-92_Inline_Wide
R1, R3, R5, R7: 1k; R_Axial_DIN0207_L6.3mm_D2.5mm_P7.62mm_Horizontal

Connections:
+3V3: A1.14 (3V3)
+6V: D1.2 (A), J1.1, J2.1, J3.1, J4.1, J5.2 (BEC), J6.2 (BEC)
/BUILTIN_LED: A1.4 (GPIO8)
/CFG: A1.3 (GPIO7), JP3.2 (B)
/LED_1: A1.12 (GPIO3), R3.1
/LED_2: A1.11 (GPIO2), R1.1
/LED_3: A1.10 (GPIO1), R5.1
/LED_4: A1.9 (GPIO0), R7.1
CH1: A1.7 (GPIO20), J5.3 (VCC)
CH2: A1.6 (GPIO10), J6.3 (VCC)
GND: A1.15 (GND), J5.1 (GND), J6.1 (GND), JP3.1 (A), Q1.1 (E), Q2.1 (E), Q3.1 (E), Q4.1 (E)
unnamed: J1.2, Q1.3 (C)
unnamed: J2.2, Q2.3 (C)
unnamed: J3.2, Q3.3 (C)
unnamed: J4.2, Q4.3 (C)
unnamed: Q1.2 (B), R3.2
unnamed: Q2.2 (B), R1.2
unnamed: Q3.2 (B), R5.2
unnamed: Q4.2 (B), R7.2
VBUS: A1.16 (5v), D1.1 (K)

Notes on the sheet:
Usage of JP1 is intended to allow linking both connectors in the 2-3 position, making it a Y-cable harness. If you require both channels, keep it in the default 1-2 position.

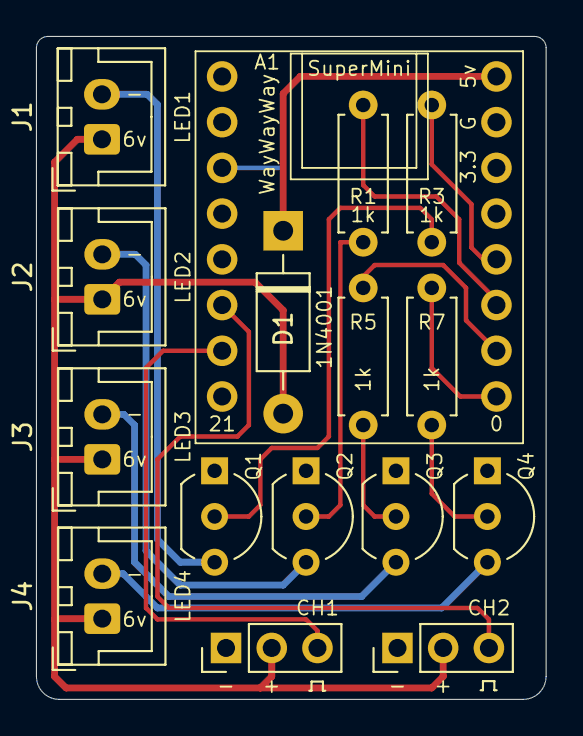
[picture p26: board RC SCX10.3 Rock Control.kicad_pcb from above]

Board: 2 copper layers, 28.3 x 36.8 mm, 17 parts (1 on the bottom side), 18 nets.

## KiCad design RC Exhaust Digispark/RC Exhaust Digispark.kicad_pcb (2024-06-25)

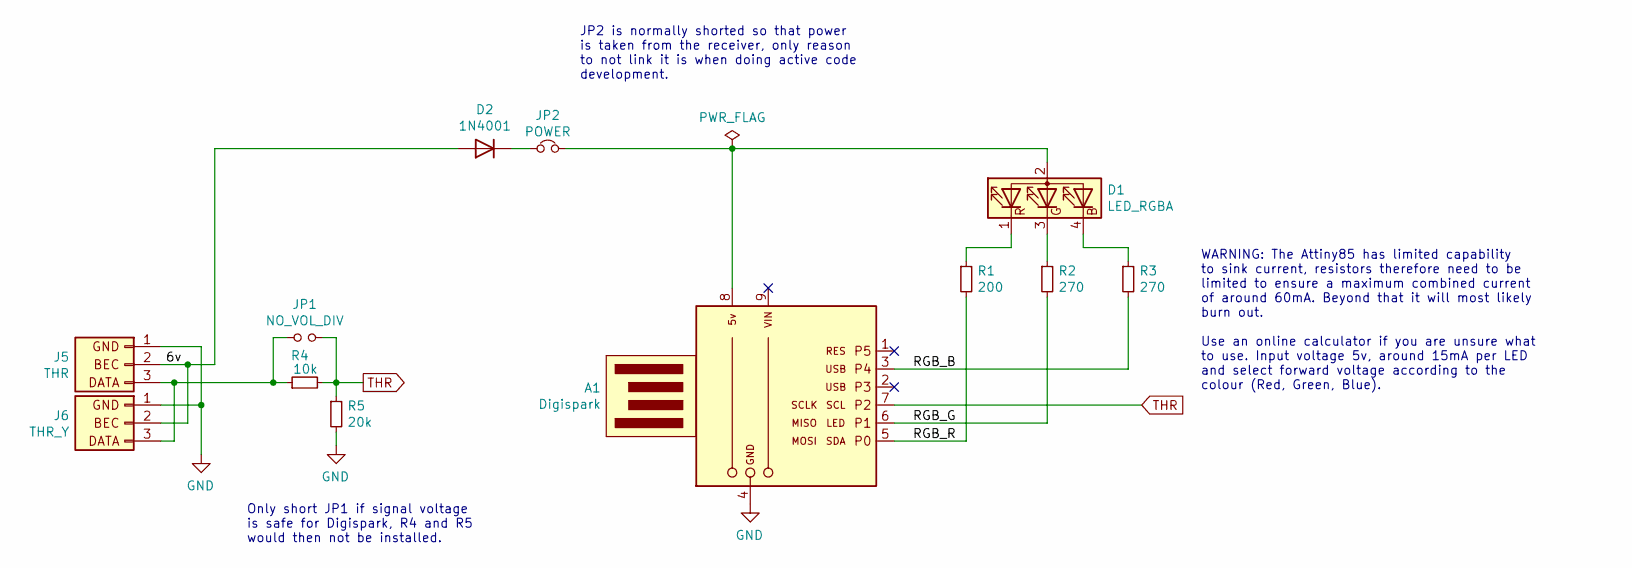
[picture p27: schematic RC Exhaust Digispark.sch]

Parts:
A1: Digispark
D1: LED_RGBA; JST_XH_B4B-XH-A_1x04_P2.50mm_Vertical
D2: 1N4001; D_DO-41_SOD81_P10.16mm_Horizontal
J5: THR; PinHeader_1x03_P2.54mm_Vertical
J6: THR_Y; PinHeader_1x03_P2.54mm_Vertical
JP1: NO_VOL_DIV; bridge_open
JP2: POWER; bridge
R1: 200; R_Axial_DIN0207_L6.3mm_D2.5mm_P7.62mm_Horizontal
R2, R3: 270; R_Axial_DIN0207_L6.3mm_D2.5mm_P7.62mm_Horizontal
R4: 10k; R_Axial_DIN0207_L6.3mm_D2.5mm_P7.62mm_Horizontal
R5: 20k; R_Axial_DIN0207_L6.3mm_D2.5mm_P7.62mm_Horizontal

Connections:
/6v: D2.2 (A), J5.2 (BEC), J6.2 (BEC)
/RGB_B: A1.3 (P4), R3.2
/RGB_G: A1.6 (P1), R2.2
/RGB_R: A1.5 (P0), R1.2
GND: A1.4 (GND), J5.1 (GND), J6.1 (GND), R5.2
unnamed: A1.8 (5v), D1.2 (A), JP2.2
unnamed: D1.1 (RK), R1.1
unnamed: D1.3 (GK), R2.1
unnamed: D1.4 (BK), R3.1
unnamed: D2.1 (K), JP2.1
unnamed: J5.3 (VCC), J6.3 (VCC), JP1.1, R4.1
THR: A1.7 (P2), JP1.2, R4.2, R5.1

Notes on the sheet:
Only short JP1 if signal voltage is safe for Digispark, R4 and R5 would then not be installed.
JP2 is normally shorted so that power is taken from the receiver, only reason to not link it is when doing active code development.
WARNING: The Attiny85 has limited capability to sink current, resistors therefore need to be limited to ensure a maximum combined current of around 60mA. Beyond that it will most likely burn out. Use an online calculator if you are unsure what to use. Input voltage 5v, around 15mA per LED and selec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

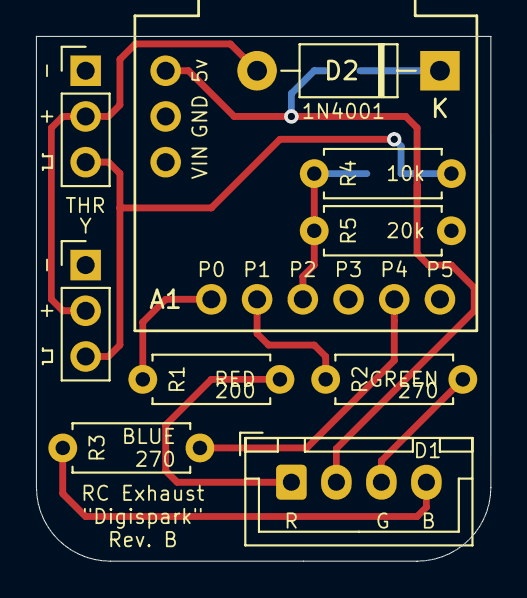
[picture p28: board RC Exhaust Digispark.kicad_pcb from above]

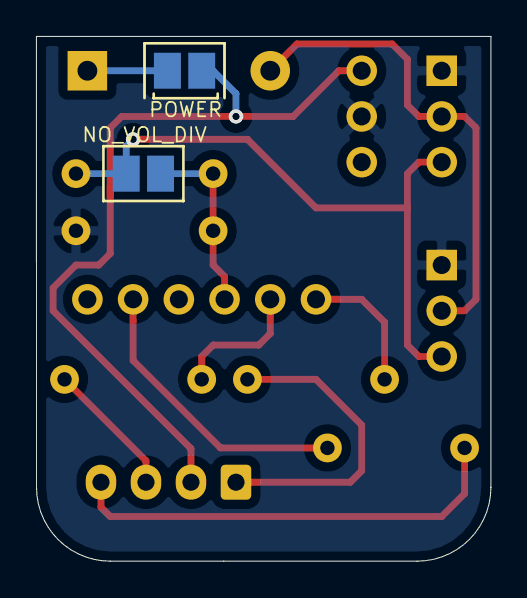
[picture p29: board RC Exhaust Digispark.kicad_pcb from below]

Board: 2 copper layers, 25.2 x 29.2 mm, 12 parts (2 on the bottom side), 12 nets.

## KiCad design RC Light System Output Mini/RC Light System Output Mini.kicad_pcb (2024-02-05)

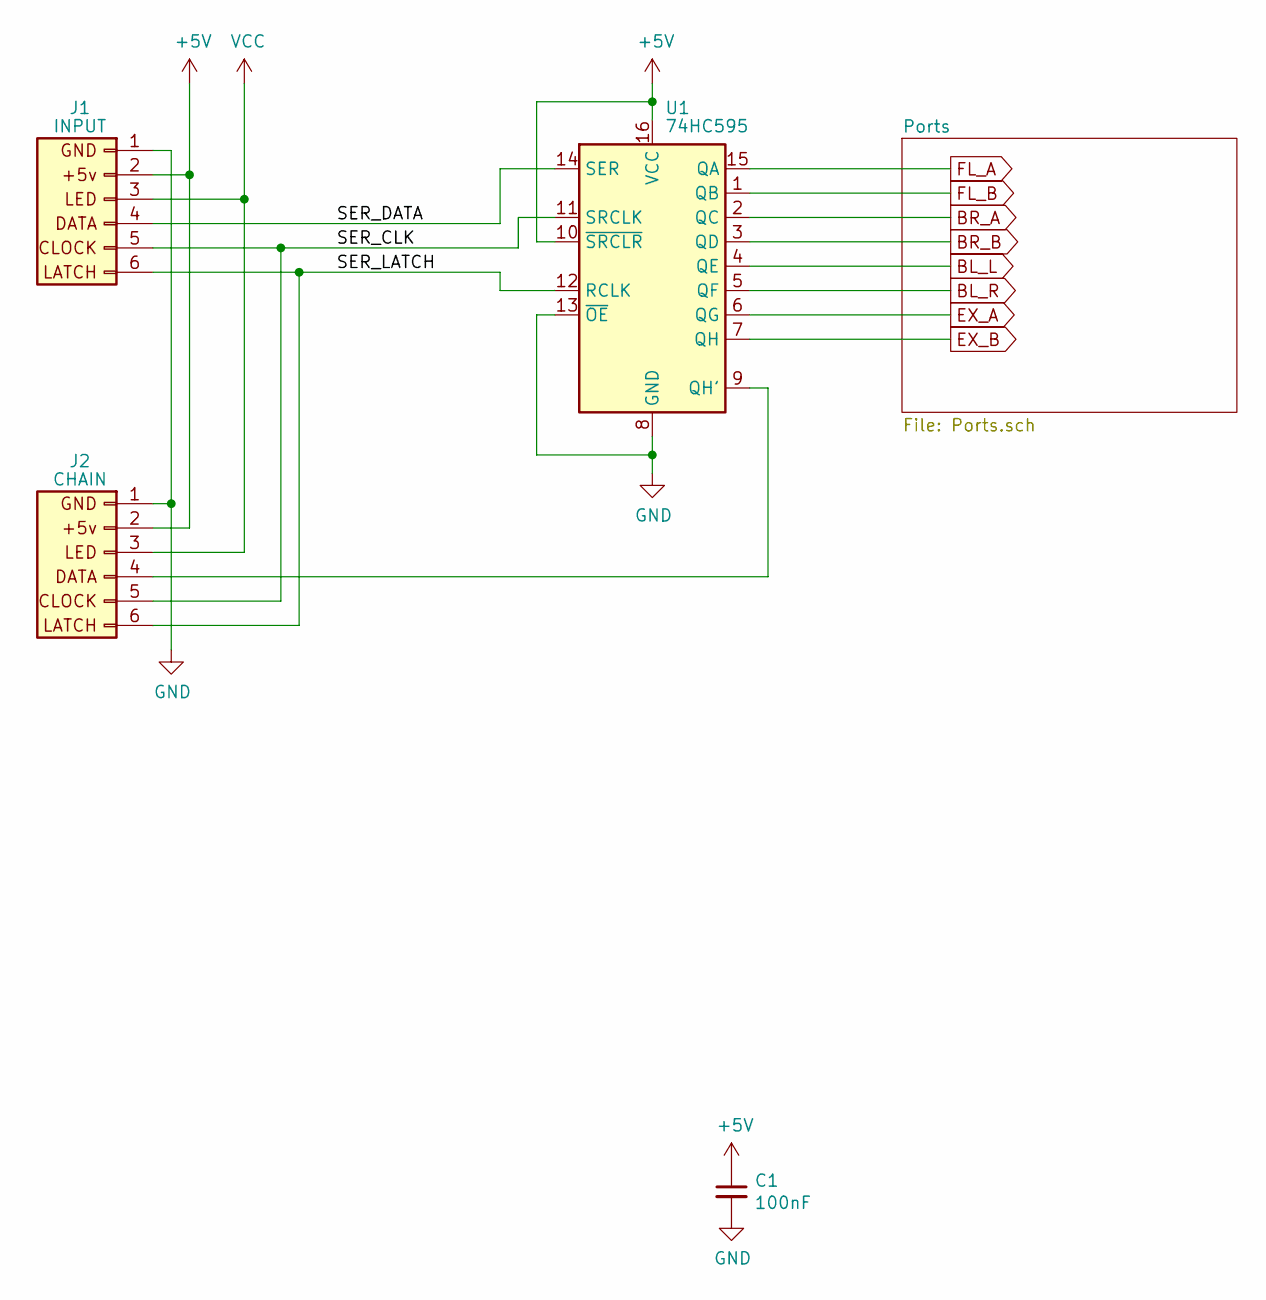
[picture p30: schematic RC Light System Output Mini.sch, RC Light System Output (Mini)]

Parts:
C1: 100nF; C_Disc_D4.7mm_W2.5mm_P5.00mm
J1: INPUT; JST_XH_B6B-XH-A_1x06_P2.50mm_Vertical
J2: CHAIN; JST_XH_B6B-XH-A_1x06_P2.50mm_Vertical
U1: 74HC595; DIP-16_W7.62mm_Socket_LongPads

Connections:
+5V: C1.1, J1.2 (+5V), J2.2 (+5V), U1.10 (~SRCLR), U1.16 (VCC)
/SER_CLK: J1.5 (CLOCK), J2.5 (CLOCK), U1.11 (SRCLK)
/SER_DATA: J1.4 (DATA), U1.14 (SER)
/SER_LATCH: J1.6 (LATCH), J2.6 (LATCH), U1.12 (RCLK)
BL_L: U1.4 (QE); also elsewhere on the board
BL_R: U1.5 (QF); also elsewhere on the board
BR_A: U1.2 (QC); also elsewhere on the board
BR_B: U1.3 (QD); also elsewhere on the board
EX_A: U1.6 (QG); also elsewhere on the board
EX_B: U1.7 (QH); also elsewhere on the board
FL_A: U1.15 (QA); also elsewhere on the board
FL_B: U1.1 (QB); also elsewhere on the board
GND: C1.2, J1.1 (GND), J2.1 (GND), U1.8 (GND), U1.13 (~OE); also elsewhere on the board
unnamed: J2.4 (DATA), U1.9 (QH')
VCC: J1.3 (LED), J2.3 (LED)

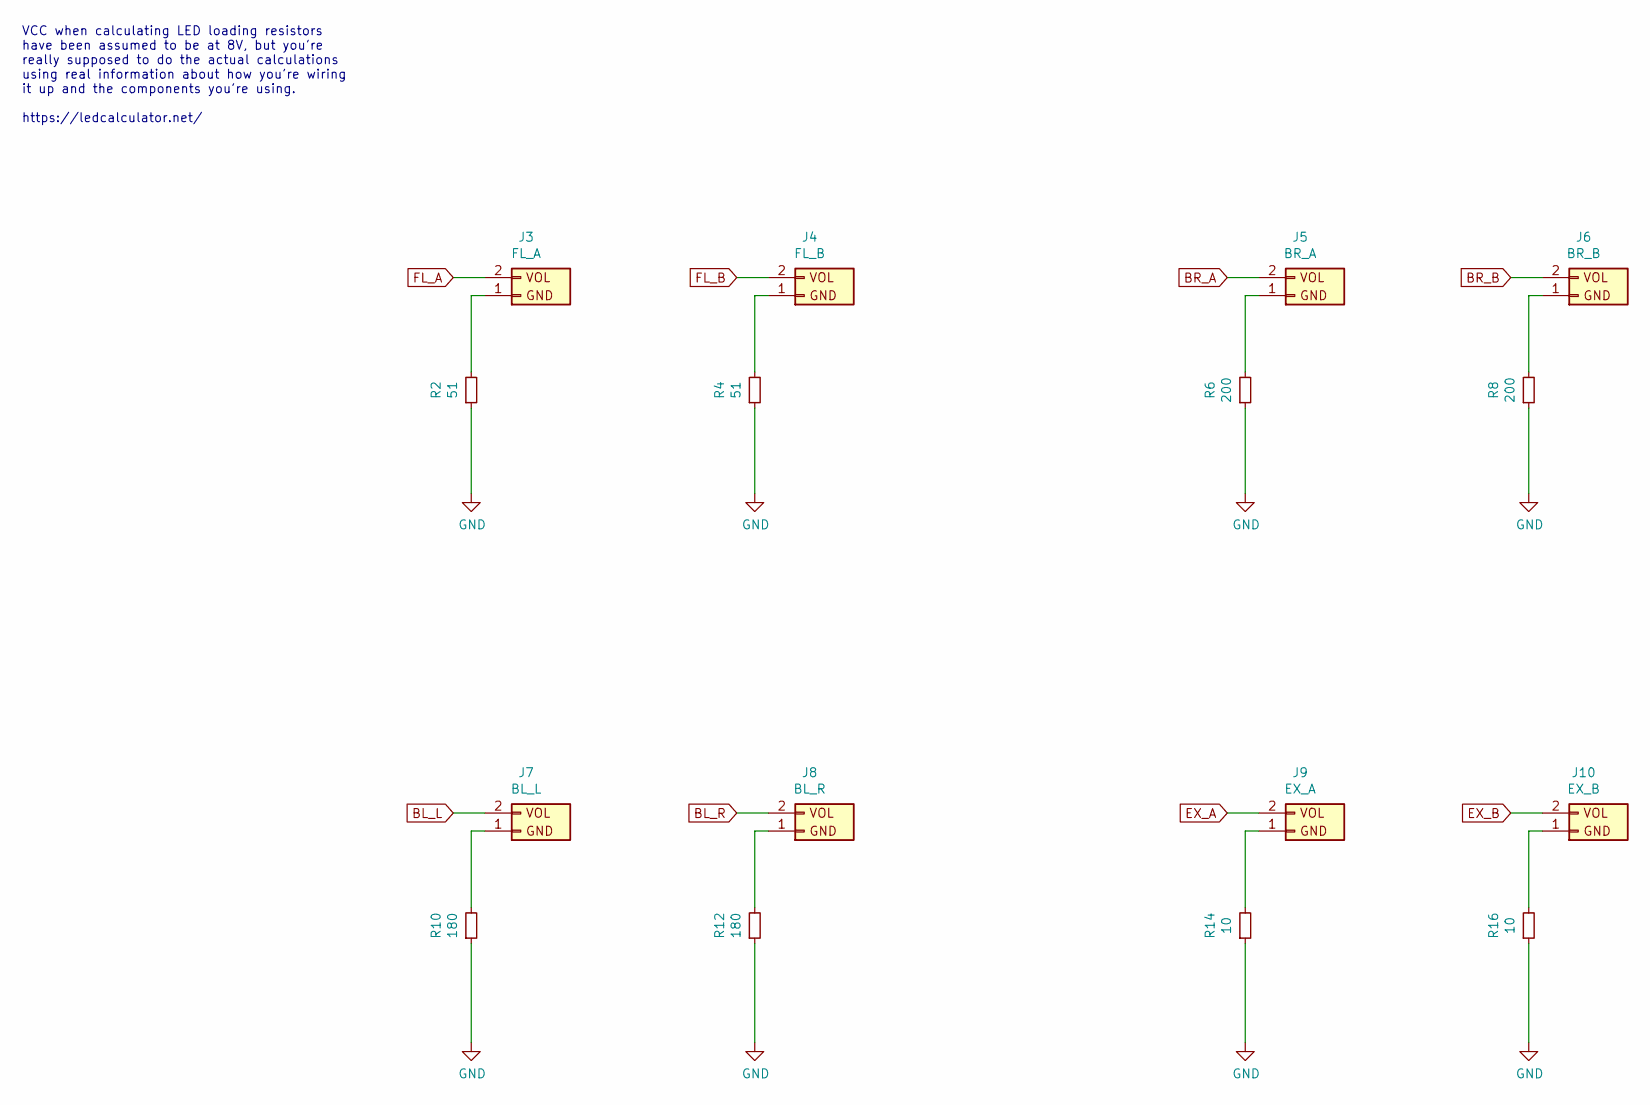
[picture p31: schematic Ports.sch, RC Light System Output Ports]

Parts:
J3: FL_A; JST_XH_B2B-XH-A_1x02_P2.50mm_Vertical
J4: FL_B; JST_XH_B2B-XH-A_1x02_P2.50mm_Vertical
J5: BR_A; JST_XH_B2B-XH-A_1x02_P2.50mm_Vertical
J6: BR_B; JST_XH_B2B-XH-A_1x02_P2.50mm_Vertical
J7: BL_L; JST_XH_B2B-XH-A_1x02_P2.50mm_Vertical
J8: BL_R; JST_XH_B2B-XH-A_1x02_P2.50mm_Vertical
J9: EX_A; JST_XH_B2B-XH-A_1x02_P2.50mm_Vertical
J10: EX_B; JST_XH_B2B-XH-A_1x02_P2.50mm_Vertical
R2, R4: 51; R_Axial_DIN0207_L6.3mm_D2.5mm_P7.62mm_Horizontal
R6, R8: 200; R_Axial_DIN0207_L6.3mm_D2.5mm_P7.62mm_Horizontal
R10, R12: 180; R_Axial_DIN0207_L6.3mm_D2.5mm_P7.62mm_Horizontal
R14, R16: 10; R_Axial_DIN0207_L6.3mm_D2.5mm_P7.62mm_Horizontal

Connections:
BL_L: J7.2 (+5V); also elsewhere on the board
BL_R: J8.2 (+5V); also elsewhere on the board
BR_A: J5.2 (+5V); also elsewhere on the board
BR_B: J6.2 (+5V); also elsewhere on the board
EX_A: J9.2 (+5V); also elsewhere on the board
EX_B: J10.2 (+5V); also elsewhere on the board
FL_A: J3.2 (+5V); also elsewhere on the board
FL_B: J4.2 (+5V); also elsewhere on the board
GND: R2.1, R4.1, R6.1, R8.1, R10.1, R12.1, R14.1, R16.1; also elsewhere on the board
unnamed: J3.1 (GND), R2.2
unnamed: J4.1 (GND), R4.2
unnamed: J5.1 (GND), R6.2
unnamed: J6.1 (GND), R8.2
unnamed: J7.1 (GND), R10.2
unnamed: J8.1 (GND), R12.2
unnamed: J9.1 (GND), R14.2
unnamed: J10.1 (GND), R16.2

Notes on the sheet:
VCC when calculating LED loading resistors have been assumed to be at 8V, but you're really supposed to do the actual calculations using real information about how you're wiring it up and the components you're using. https://ledcalculator.net/


Board: 2 copper layers, 39.4 x 41.3 mm, 20 parts (0 on the bottom side), 23 nets.

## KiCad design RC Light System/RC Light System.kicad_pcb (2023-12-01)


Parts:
A1: Arduino Pro Micro; Arduino_Pro_Micro
D1: 1N4001; D_DO-41_SOD81_P10.16mm_Horizontal
J1: OUTPUT 1; JST_XH_B6B-XH-A_1x06_P2.50mm_Vertical
J2: OUTPUT 2; JST_XH_B6B-XH-A_1x06_P2.50mm_Vertical
J3: THR_IN; PinSocket_1x03_P2.54mm_Vertical
J4: THR_OUT; PinHeader_1x03_P2.54mm_Vertical
J5: STR_IN; PinSocket_1x03_P2.54mm_Vertical
J6: STR_OUT; PinHeader_1x03_P2.54mm_Vertical
J7: AUX_IN; PinSocket_1x03_P2.54mm_Vertical
J8: AUX_OUT; PinHeader_1x03_P2.54mm_Vertical
J9: THR_Y; PinHeader_1x03_P2.54mm_Vertical
J10: BIND_IN; PinSocket_1x03_P2.54mm_Vertical
J11: STR_Y; PinHeader_1x03_P2.54mm_Vertical
J12: AUX_Y; PinHeader_1x03_P2.54mm_Vertical
JP1: BIND; PinHeader_1x02_P2.54mm_Vertical
JP2: POWER; bridge
R3, R5, R7: 10k; R_Axial_DIN0207_L6.3mm_D2.5mm_P7.62mm_Horizontal
R4, R6, R8: 20k; R_Axial_DIN0207_L6.3mm_D2.5mm_P7.62mm_Horizontal
TP1: +5v; Testpoint
TP2: GND; Testpoint
TP3: LED; Testpoint

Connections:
/+5v: A1.21 (VCC), J1.2 (+5V), J2.2 (+5V), JP2.2, TP1.1
/+6v: D1.2 (A), J1.3 (LED), J2.3 (LED), J3.2 (BEC), J4.2 (BEC), J5.2 (BEC), J6.2 (BEC), J7.2 (BEC), J8.2 (BEC), J9.2 (BEC), J10.2 (BEC), J11.2 (BEC), J12.2 (BEC), TP3.1
/SER_CLK_1: A1.10 (D7), J1.5 (CLOCK)
/SER_CLK_2: A1.8 (D5), J2.5 (CLOCK)
/SER_DATA: A1.11 (D8), J1.4 (DATA), J2.4 (DATA)
/SER_LATCH: A1.7 (D4), J1.6 (LATCH), J2.6 (LATCH)
AUX: A1.2 (RXI), R7.1
GND: A1.3 (GND), A1.4 (GND), A1.23 (GND), J1.1 (GND), J2.1 (GND), J3.1 (GND), J4.1 (GND), J5.1 (GND), J6.1 (GND), J7.1 (GND), J8.1 (GND), J9.1 (GND), J10.1 (GND), J11.1 (GND), J12.1 (GND), JP1.1, R4.2, R6.2, R8.2, TP2.1
unnamed: D1.1 (K), JP2.1
unnamed: J3.3 (VCC), J4.3 (VCC), J9.3 (VCC), R3.2, R4.1
unnamed: J10.3 (VCC), JP1.2
unnamed: J5.3 (VCC), J6.3 (VCC), J11.3 (VCC), R5.2, R6.1
unnamed: J7.3 (VCC), J8.3 (VCC), J12.3 (VCC), R7.2, R8.1
STR: A1.6 (D3), R5.1
THR: A1.5 (D2), R3.1



Board: 2 copper layers, 36.2 x 41.3 mm, 25 parts (4 on the bottom side), 15 nets.

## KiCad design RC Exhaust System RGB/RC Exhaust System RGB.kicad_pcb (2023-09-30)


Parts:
C1, C3: 100nF; C_Disc_D4.7mm_W2.5mm_P5.00mm
C2: 2.2uF; CP_Radial_D4.0mm_P2.00mm
D1: LED_RGBA; JST_XH_B4B-XH-A_1x04_P2.50mm_Vertical
J5: THR; PinHeader_1x03_P2.54mm_Vertical
J6: THR_Y; PinHeader_1x03_P2.54mm_Vertical
R1, R2, R3: 270; R_Axial_DIN0207_L6.3mm_D2.5mm_P7.62mm_Horizontal
R4: 10k; R_Axial_DIN0207_L6.3mm_D2.5mm_P7.62mm_Horizontal
R5: 20k; R_Axial_DIN0207_L6.3mm_D2.5mm_P7.62mm_Horizontal
U1: L4931CZ50; L4931CZ50_TO-92_Inline_Wide
U2: ATtiny85-20PU; DIP-8_W7.62mm

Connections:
+5V: C2.1, C3.1, D1.2 (A), U1.1 (OUT), U2.8 (VCC)
GND: C1.2, C2.2, C3.2, J5.1 (GND), J6.1 (GND), R5.2, U1.2 (GND), U2.4 (GND)
unnamed: D1.1 (RK), R1.1
unnamed: D1.3 (GK), R2.1
unnamed: D1.4 (BK), R3.1
unnamed: J5.3 (VCC), J6.3 (VCC), R4.1
unnamed: R1.2, U2.5 (AREF/PB0)
unnamed: R2.2, U2.6 (PB1)
unnamed: R3.2, U2.3 (XTAL2/PB4)
THR: R4.2, R5.1, U2.7 (PB2)
VCC: C1.1, J5.2 (BEC), J6.2 (BEC), U1.3 (IN)


Board: 2 copper layers, 20.8 x 37.2 mm, 13 parts (0 on the bottom side), 11 nets.

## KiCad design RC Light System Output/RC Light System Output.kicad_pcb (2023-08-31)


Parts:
C1: 100nF; C_Disc_D4.7mm_W2.5mm_P5.00mm
J1: INPUT; JST_XH_B6B-XH-A_1x06_P2.50mm_Vertical
J2: CHAIN; JST_XH_B6B-XH-A_1x06_P2.50mm_Vertical
U1: 74HC595; DIP-16_W7.62mm_Socket_LongPads

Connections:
+5V: C1.1, J1.2 (+5V), J2.2 (+5V), U1.10 (~SRCLR), U1.16 (VCC)
/SER_CLK: J1.5 (CLOCK), J2.5 (CLOCK), U1.11 (SRCLK)
/SER_DATA: J1.4 (DATA), U1.14 (SER)
/SER_LATCH: J1.6 (LATCH), J2.6 (LATCH), U1.12 (RCLK)
BL_L: U1.4 (QE); also elsewhere on the board
BL_R: U1.5 (QF); also elsewhere on the board
BR_A: U1.2 (QC); also elsewhere on the board
BR_B: U1.3 (QD); also elsewhere on the board
EX_A: U1.6 (QG); also elsewhere on the board
EX_B: U1.7 (QH); also elsewhere on the board
FL_A: U1.15 (QA); also elsewhere on the board
FL_B: U1.1 (QB); also elsewhere on the board
GND: C1.2, J1.1 (GND), J2.1 (GND), U1.8 (GND), U1.13 (~OE); also elsewhere on the board
unnamed: J2.4 (DATA), U1.9 (QH')
VCC: J1.3 (VCC), J2.3 (VCC); also elsewhere on the board

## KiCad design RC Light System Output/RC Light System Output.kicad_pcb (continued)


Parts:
J3: FL_A; JST_XH_B2B-XH-A_1x02_P2.50mm_Vertical
J4: FL_B; JST_XH_B2B-XH-A_1x02_P2.50mm_Vertical
J5: BR_A; JST_XH_B2B-XH-A_1x02_P2.50mm_Vertical
J6: BR_B; JST_XH_B2B-XH-A_1x02_P2.50mm_Vertical
J7: BL_L; JST_XH_B2B-XH-A_1x02_P2.50mm_Vertical
J8: BL_R; JST_XH_B2B-XH-A_1x02_P2.50mm_Vertical
J9: EX_A; JST_XH_B2B-XH-A_1x02_P2.50mm_Vertical
J10: EX_B; JST_XH_B2B-XH-A_1x02_P2.50mm_Vertical
JP1: FL_LINK; bridge_open
JP2: BR_LINK; bridge_open
JP3: BL_LINK; bridge_open
JP4: EX_LINK; bridge_open
Q1, Q2, Q3, Q4, Q5, Q6, Q7, Q8: 2N2222; TO-92_HandSolder
R1, R3, R5, R7, R9, R11, R13, R15: 4k7; R_Axial_DIN0207_L6.3mm_D2.5mm_P7.62mm_Horizontal
R2, R4: 51; R_Axial_DIN0207_L6.3mm_D2.5mm_P7.62mm_Horizontal
R6, R8: 200; R_Axial_DIN0207_L6.3mm_D2.5mm_P7.62mm_Horizontal
R10, R12: 180; R_Axial_DIN0207_L6.3mm_D2.5mm_P7.62mm_Horizontal
R14, R16: 10; R_Axial_DIN0207_L6.3mm_D2.5mm_P7.62mm_Horizontal
RN1: 10k; R_Array_SIP9

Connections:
BL_L: R9.2, RN1.6 (R5); also elsewhere on the board
BL_R: R11.2, RN1.7 (R6); also elsewhere on the board
BR_A: R5.2, RN1.4 (R3); also elsewhere on the board
BR_B: R7.2, RN1.5 (R4); also elsewhere on the board
EX_A: R13.2, RN1.8 (R7); also elsewhere on the board
EX_B: R15.2, RN1.9 (R8); also elsewhere on the board
FL_A: R1.2, RN1.2 (R1); also elsewhere on the board
FL_B: R3.2, RN1.3 (R2); also elsewhere on the board
GND: Q1.3 (E), Q2.3 (E), Q3.3 (E), Q4.3 (E), Q5.3 (E), Q6.3 (E), Q7.3 (E), Q8.3 (E), RN1.1 (common); also elsewhere on the board
unnamed: J3.1 (GND), JP1.2 (B), R2.2
unnamed: J4.1 (GND), JP1.1 (A), R4.2
unnamed: J5.1 (GND), JP2.2 (B), R6.2
unnamed: J6.1 (GND), JP2.1 (A), R8.2
unnamed: J7.1 (GND), JP3.2 (B), R10.2
unnamed: J8.1 (GND), JP3.1 (A), R12.2
unnamed: J9.1 (GND), JP4.2 (B), R14.2
unnamed: J10.1 (GND), JP4.1 (A), R16.2
unnamed: Q1.1 (C), R2.1
unnamed: Q1.2 (B), R1.1
unnamed: Q2.1 (C), R4.1
unnamed: Q2.2 (B), R3.1
unnamed: Q3.1 (C), R6.1
unnamed: Q3.2 (B), R5.1
unnamed: Q4.1 (C), R8.1
unnamed: Q4.2 (B), R7.1
unnamed: Q5.1 (C), R10.1
unnamed: Q5.2 (B), R9.1
unnamed: Q6.1 (C), R12.1
unnamed: Q6.2 (B), R11.1
unnamed: Q7.1 (C), R14.1
unnamed: Q7.2 (B), R13.1
unnamed: Q8.1 (C), R16.1
unnamed: Q8.2 (B), R15.1
VCC: J3.2 (+5V), J4.2 (+5V), J5.2 (+5V), J6.2 (+5V), J7.2 (+5V), J8.2 (+5V), J9.2 (+5V), J10.2 (+5V); also elsewhere on the board

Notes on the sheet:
When linking the ports, you would generally not install these parts.
Assuming 2 WHITE LEDs in series, 3.5V voltage drop and 20mA current.
When linked, double R2/R4 value as starting point. Unlinked, 2x LEDs for FL_A and FL_B if needed.
Assuming 2 RED LEDs in series, 2.1V voltage drop and 20mA current.
When linked, double R6/R8 value as starting point. Unlinked, 2x LEDs for BR_A and BR_B if needed.
Assuming 2 ORANGE LEDs in series, 2.2V voltage drop and 20mA current.
When linked, double R10/R12 value as starting point. Unlinked, 2x LEDs for BL_L and BL_R if needed.
VCC when calculating LED loading resistors have been assumed to be at 8V, but you're really supposed to do the actual calculations using real information about how you're wiring it up and the components you're using. https://ledcalculator.net/
Assuming LEDs with resistors already in the lead, resistor as failsafe.
There should be a 1 Ohm resistor between the emitter and ground here, but it's large enough as it is. Use transistors somewhat equal to eachother. I'll add it to SMD-version if I get around to it. If in doubt, don't link the pairs.



Board: 2 copper layers, 41.3 x 54.0 mm, 41 parts (4 on the bottom side), 39 nets.

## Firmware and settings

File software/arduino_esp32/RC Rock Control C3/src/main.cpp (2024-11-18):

#include <Arduino.h>
#include <ServoInput.h>
#include "constants.h"
#include "settings.h"

const int ch1_signal_pin = PIN_CH1;
ServoInputPin<ch1_signal_pin> channel1(CH1_PULSE_MIN, CH1_PULSE_MAX);

const int ch2_signal_pin = PIN_CH2;
ServoInputPin<ch2_signal_pin> channel2(CH2_PULSE_MIN, CH2_PULSE_MAX);

struct Channel {
  int value;          // Channel value
  int last_value;     // Previous value read
  bool changed;       // Value changed during this loop
  byte state;         // Interpreted channel state
  bool available;     // Pulses observed?
};
Channel CH1 = { 0, 0, true, STATE_IDLE, false };
Channel CH2 = { 0, 0, true, STATE_IDLE, false };

struct LED {
  const uint8_t pin;  // Physical pin
  const uint8_t low;  // Weak light value
  const uint8_t high; // Strong light value

  int value;          // Brightness we want it to have
  int actual;         // Brightness we're currently at, fading towards value
};

LED LED_FRONT_LEFT = { PIN_LED_1, LED_1_LOW, LED_1_HIGH, LED_1_DEFAULT, -1 };  // LED1
LED LED_REAR_LEFT = { PIN_LED_2, LED_2_LOW, LED_2_HIGH, LED_2_DEFAULT, -1 };   // LED2
LED LED_REAR_RIGHT = { PIN_LED_3, LED_3_LOW, LED_3_HIGH, LED_3_DEFAULT, -1 };  // LED3
LED LED_FRONT_RIGHT = { PIN_LED_4, LED_4_LOW, LED_4_HIGH, LED_4_DEFAULT, -1 }; // LED4

bool builtin_value = false;
unsigned long builtin_timer = -1;

uint8_t current_mode = DEFAULT_MODE;


void set_led(LED *led, int new_value) {
  led->value = new_value;
}


void write_led(LED *led, int new_value) {
  if (led->actual == -1 || led->actual != new_value) {
    led->actual = new_value;
    analogWrite(led->pin, new_value);
  }
}


int map_value(Channel *channel, bool available, long new_value) {
  channel->last_value = channel->value;
  channel->value = new_value;
  channel->changed = (channel->last_value != channel->value);
  channel->available = available;

  if (channel->changed) {
    channel->state = STATE_IDLE;
    if (channel->value > LOW_THRESHOLD) channel->state = STATE_POSITIVE;
    if (channel->value < -(LOW_THRESHOLD)) channel->state = STATE_NEGATIVE;
  }
  return STATE_INVALID;
}


/* This will read channel values, but take note that current_value will
 * read as 0 (stick in neutral position). Possiblywhile a signal is not
 * actually present, such as when the cable has fallen out.
 */
void read_values() {
  // Steering
  map_value(&CH1, channel1.available(), channel1.map(-100, 100));

  // Throttle
  // Note: channel2 is assumed to be available, obviously won't work otherwise
  map_value(&CH2, true, channel2.map(-100, 100));
}


//variables to keep track of the timing of recent interrupts
unsigned long switch_updated = 0;  
unsigned long last_switch_time = 0; 
bool switch_was_pushed = false;
void IRAM_ATTR switch_pushed() {
  switch_updated = millis();
  if (switch_updated - last_switch_time > 250) {
    switch_was_pushed = true;
    last_switch_time = switch_updated;
  }
}


void setup_led(LED *led) {
  pinMode(led->pin, OUTPUT);
  write_led(led, 0);
}


void setup() {
  pinMode(PIN_BOOT, INPUT_PULLUP);
  attachInterrupt(PIN_BOOT, switch_pushed, FALLING);

  pinMode(PIN_CFG, INPUT_PULLUP);

  pinMode(LED_BUILTIN, OUTPUT);
  digitalWrite(LED_BUILTIN, HIGH);

  setup_led(&LED_FRONT_LEFT);
  setup_led(&LED_REAR_LEFT);
  setup_led(&LED_REAR_RIGHT);
  setup_led(&LED_FRONT_RIGHT);

  channel1.attach();
  channel2.attach();
}


void process_switch() {
  if (switch_was_pushed) {
    switch_was_pushed = false;

    // actually do things
    if (current_mode == MODE_LAST) {
      current_mode = MODE_DISABLED;
    } else {
      current_mode++;
    }
  }
}


int next_led_value(int current, int max) {
  current = current + LED_STEPS;
  if (current > max) current = max;
  return current;
}


int previous_led_value(int current) {
  current = current - LED_STEPS;
  if (current < 0) current = 0;
  return current;
}


void update_led(LED *led) {
  if (led->value > led->actual) {
    write_led(led, next_led_value(led->actual, led->high));
  }
  if (led->value < led->actual) {
    write_led(led, previous_led_value(led->actual));
  }
}


unsigned long breathing_timer = -1;
unsigned long breathing_diff;
bool breathing_value = true;
void process_breathing() {
  if (breathing_timer == -1) {
    breathing_timer = millis();

    breathing_value = false;
    set_led(&LED_FRONT_LEFT, breathing_value ? LED_FRONT_LEFT.high : LED_FRONT_LEFT.low);
    set_led(&LED_REAR_LEFT, breathing_value ? LED_REAR_LEFT.high : LED_REAR_LEFT.low);
    set_led(&LED_REAR_RIGHT, breathing_value ? LED_REAR_RIGHT.high : LED_REAR_RIGHT.low);
    set_led(&LED_FRONT_RIGHT, breathing_value ? LED_FRONT_RIGHT.high : LED_FRONT_RIGHT.low);
  }


  if ((millis() - breathing_timer) > BREATHING_SPEED) {
    breathing_timer = millis();
    breathing_value = !breathing_value;
  }


  breathing_diff = millis() - breathing_timer;
  if (breathing_diff > BREATHING_SPEED) breathing_diff = BREATHING_SPEED;
  if (breathing_value) {
    set_led(&LED_FRONT_LEFT, map(breathing_diff, 0, BREATHING_SPEED, LED_1_HIGH, LED_1_LOW));
    set_led(&LED_REAR_LEFT, map(breathing_diff, 0, BREATHING_SPEED, LED_2_HIGH, LED_2_LOW));
    set_led(&LED_REAR_RIGHT, map(breathing_diff, 0, BREATHING_SPEED, LED_3_HIGH, LED_3_LOW));
    set_led(&LED_FRONT_RIGHT, map(breathing_diff, 0, BREATHING_SPEED, LED_4_HIGH, LED_4_LOW));
  } else {
    set_led(&LED_FRONT_LEFT, map(breathing_diff, 0, BREATHING_SPEED, LED_1_LOW, LED_1_HIGH));
    set_led(&LED_REAR_LEFT, map(breathing_diff, 0, BREATHING_SPEED, LED_2_LOW, LED_2_HIGH));
    set_led(&LED_REAR_RIGHT, map(breathing_diff, 0, BREATHING_SPEED, LED_3_LOW, LED_3_HIGH));
    set_led(&LED_FRONT_RIGHT, map(breathing_diff, 0, BREATHING_SPEED, LED_4_LOW, LED_4_HIGH));
  }
}


void process_dynamic_dual() {
  // going forward
  if (CH2.state == STATE_POSITIVE) {
    switch (CH1.state) {
      case STATE_POSITIVE: // while turning right
        set_led(&LED_FRONT_LEFT, map(CH2.value, 0, 100, LED_FRONT_LEFT.low, LED_FRONT_LEFT.high));
        set_led(&LED_FRONT_RIGHT, map(CH1.value, 0, 100, LED_FRONT_LEFT.value, LED_FRONT_RIGHT.high));
        break;

      default:
      case STATE_IDLE:
        set_led(&LED_FRONT_LEFT, map(CH2.value, 0, 100, LED_FRONT_LEFT.low, LED_FRONT_LEFT.high));
        set_led(&LED_FRONT_RIGHT, map(CH2.value, 0, 100, LED_FRONT_RIGHT.low, LED_FRONT_RIGHT.high));
        break;

      case STATE_NEGATIVE: // while turning left
        set_led(&LED_FRONT_RIGHT, map(CH2.value, 0, 100, LED_FRONT_RIGHT.low, LED_FRONT_RIGHT.high));
        set_led(&LED_FRONT_LEFT, map(CH1.value, -100, 0, LED_FRONT_LEFT.high, LED_FRONT_RIGHT.value));
        break;
    }

    set_led(&LED_REAR_LEFT, LED_REAR_LEFT.low);
    set_led(&LED_REAR_RIGHT, LED_REAR_RIGHT.low);
    return;
  }

  // going nowhere...
  if (CH2.state == STATE_IDLE) {
    switch (CH1.state) {
      case STATE_POSITIVE: // while turning right
        set_led(&LED_FRONT_LEFT, LED_FRONT_LEFT.low);
        set_led(&LED_FRONT_RIGHT, map(CH1.value, 0, 100, LED_FRONT_RIGHT.low, LED_FRONT_RIGHT.high));
        break;

      default:
      case STATE_IDLE:
        set_led(&LED_FRONT_LEFT, LED_FRONT_LEFT.low);
        set_led(&LED_FRONT_RIGHT, LED_FRONT_RIGHT.low);
        break;

      case STATE_NEGATIVE: // while turning left
        set_led(&LED_FRONT_LEFT, map(CH1.value, -100, 0, LED_FRONT_LEFT.high, LED_FRONT_LEFT.low));
        set_led(&LED_FRONT_RIGHT, LED_FRONT_RIGHT.low);
        break;
    }

    set_led(&LED_REAR_LEFT, LED_REAR_LEFT.low);
    set_led(&LED_REAR_RIGHT, LED_REAR_RIGHT.low);
    return;
  }


  // going backwards
  if (CH2.state == STATE_NEGATIVE) {
    switch (CH1.state) {
      case STATE_POSITIVE: // while turning right
        set_led(&LED_FRONT_LEFT, LED_FRONT_LEFT.low);
        set_led(&LED_FRONT_RIGHT, map(CH1.value, 0, 100, LED_FRONT_RIGHT.low, LED_FRONT_RIGHT.high));
        break;

      default:
      case STATE_IDLE:
        set_led(&LED_FRONT_LEFT, LED_FRONT_LEFT.low);
        set_led(&LED_FRONT_RIGHT, LED_FRONT_RIGHT.low);
        break;

      case STATE_NEGATIVE: // while turning left
        set_led(&LED_FRONT_LEFT, map(CH1.value, -100, 0, LED_FRONT_LEFT.high, LED_FRONT_LEFT.low));
        set_led(&LED_FRONT_RIGHT, LED_FRONT_RIGHT.low);
        break;
    }

    set_led(&LED_REAR_LEFT, map(CH2.value, -100, 0, LED_REAR_LEFT.high, LED_REAR_LEFT.low));
    set_led(&LED_REAR_RIGHT, map(CH2.value, -100, 0, LED_REAR_RIGHT.high, LED_REAR_RIGHT.low));
    return;
  }

  // shouldn't be able to get here
  set_led(&LED_FRONT_LEFT, LED_FRONT_LEFT.low);
  set_led(&LED_FRONT_RIGHT, LED_FRONT_RIGHT.low);
  set_led(&LED_REAR_LEFT, LED_REAR_LEFT.low);
  set_led(&LED_REAR_RIGHT, LED_REAR_RIGHT.low);
}


void process_dynamic_single() {
  // going forwards
  if (CH2.state == STATE_POSITIVE) {
    set_led(&LED_FRONT_LEFT, map(CH2.value, 0, 100, LED_FRONT_LEFT.low, LED_FRONT_LEFT.high));
    set_led(&LED_FRONT_RIGHT, map(CH2.value, 0, 100, LED_FRONT_RIGHT.low, LED_FRONT_RIGHT.high));
    set_led(&LED_REAR_LEFT, LED_REAR_LEFT.low);
    set_led(&LED_REAR_RIGHT, LED_REAR_RIGHT.low);
    return;
  }

  // going nowhere...
  if (CH2.state == STATE_IDLE) {
    set_led(&LED_FRONT_LEFT, LED_FRONT_LEFT.low);
    set_led(&LED_FRONT_RIGHT, LED_FRONT_RIGHT.low);
    set_led(&LED_REAR_LEFT, LED_REAR_LEFT.low);
    set_led(&LED_REAR_RIGHT, LED_REAR_RIGHT.low);
    return;
  }

  // going backwards
  if (CH2.state == STATE_NEGATIVE) {
    set_led(&LED_FRONT_LEFT, LED_FRONT_LEFT.low);
    set_led(&LED_FRONT_RIGHT, LED_FRONT_RIGHT.low);
    set_led(&LED_REAR_LEFT, map(CH2.value, -100, 0, LED_REAR_LEFT.high, LED_REAR_LEFT.low));
    set_led(&LED_REAR_RIGHT, map(CH2.value, -100, 0, LED_REAR_RIGHT.high, LED_REAR_RIGHT.low));
    return;
  }

  // shouldn't be able to get here
  set_led(&LED_FRONT_LEFT, LED_FRONT_LEFT.low);
  set_led(&LED_FRONT_RIGHT, LED_FRONT_RIGHT.low);
  set_led(&LED_REAR_LEFT, LED_REAR_LEFT.low);
  set_led(&LED_REAR_RIGHT, LED_REAR_RIGHT.low);
}


/* LEDs will always be in their LOW setting, but will be reinforced by the
 * direction that we're travelling (up to max value). For example you'll
 * find that on 50% forward throttle the front tires will be at the halfway
 * point between low/high, but on a hard right - the right front tire will
 * be boosted up to high.
 */
void process_dynamic() {
  if (CH1.available && CH2.available) {
    process_dynamic_dual();
    // if (LED_FRONT_LEFT.value < LED_FRONT_LEFT.low) LED_FRONT_LEFT.value = LED_FRONT_LEFT.low;
    // if (LED_FRONT_RIGHT.value < LED_FRONT_RIGHT.low) LED_FRONT_RIGHT.value = LED_FRONT_RIGHT.low;
    // if (LED_REAR_LEFT.value < LED_REAR_LEFT.low) LED_REAR_LEFT.value = LED_REAR_LEFT.low;
    // if (LED_REAR_RIGHT.value < LED_REAR_RIGHT.low) LED_REAR_RIGHT.value = LED_REAR_RIGHT.low;
  } else {
    process_dynamic_single();
  }
}


/* LEDs will always be HIGH in the direction we're currently travelling in,
 * but the opposite end of the car will fade towards the low value. The dual
 * version will also adapt according to the direction of steering.
 */
void process_inverted_dual() {
  // going forward
  if (CH2.state == STATE_POSITIVE) {
    switch (CH1.state) {
      case STATE_POSITIVE: // while turning right
        set_led(&LED_FRONT_RIGHT, map(CH2.value, 0, 100, LED_FRONT_RIGHT.high, LED_FRONT_RIGHT.low));
        set_led(&LED_FRONT_LEFT, map(CH1.value, 0, 100, LED_FRONT_RIGHT.value, LED_FRONT_RIGHT.low));
        break;

      default:
      case STATE_IDLE:
        set_led(&LED_FRONT_LEFT, map(CH2.value, 0, 100, LED_FRONT_LEFT.high, LED_FRONT_LEFT.low));
        set_led(&LED_FRONT_RIGHT, map(CH2.value, 0, 100, LED_FRONT_RIGHT.high, LED_FRONT_RIGHT.low));
        break;

      case STATE_NEGATIVE: // while turning left
        set_led(&LED_FRONT_LEFT, map(CH2.value, 0, 100, LED_FRONT_RIGHT.high, LED_FRONT_LEFT.low));
        set_led(&LED_FRONT_RIGHT, map(CH1.value, -100, 0, LED_FRONT_RIGHT.low, LED_FRONT_LEFT.value));
        break;
    }

    set_led(&LED_REAR_LEFT, map(CH2.value, 0, 100, LED_REAR_LEFT.high, LED_REAR_LEFT.low));
    set_led(&LED_REAR_RIGHT, map(CH2.value, 0, 100, LED_REAR_RIGHT.high, LED_REAR_RIGHT.low));
    return;
  }

  // going nowhere...
  if (CH2.state == STATE_IDLE) {
    switch (CH1.state) {
      case STATE_POSITIVE: // while turning right
        set_led(&LED_FRONT_LEFT, map(CH1.value, 0, 100, LED_FRONT_LEFT.high, LED_FRONT_LEFT.low));
        set_led(&LED_FRONT_RIGHT, LED_FRONT_RIGHT.high);
        break;

      default:
      case STATE_IDLE:
        set_led(&LED_FRONT_LEFT, LED_FRONT_LEFT.high);
        set_led(&LED_FRONT_RIGHT, LED_FRONT_RIGHT.high);
        break;

      case STATE_NEGATIVE: // while turning left
        set_led(&LED_FRONT_LEFT, LED_FRONT_LEFT.high);
        set_led(&LED_FRONT_RIGHT, map(CH1.value, -100, 0, LED_FRONT_RIGHT.low, LED_FRONT_RIGHT.high));
        break;
    }
    set_led(&LED_REAR_LEFT, LED_REAR_LEFT.high);
    set_led(&LED_REAR_RIGHT, LED_REAR_RIGHT.high);
    return;
  }


  // going backwards
  if (CH2.state == STATE_NEGATIVE) {
    switch (CH1.state) {
      case STATE_POSITIVE: // while turning right
        set_led(&LED_FRONT_RIGHT, map(CH2.value, -100, 0, LED_FRONT_RIGHT.low, LED_FRONT_RIGHT.high));
        set_led(&LED_FRONT_LEFT, map(CH1.value, 0, 100, LED_FRONT_RIGHT.value, LED_FRONT_RIGHT.low));
        break;

      default:
      case STATE_IDLE:
        set_led(&LED_FRONT_LEFT, map(CH2.value, -100, 0, LED_FRONT_LEFT.low, LED_FRONT_LEFT.high));
        set_led(&LED_FRONT_RIGHT, map(CH2.value, -100, 0, LED_FRONT_RIGHT.low, LED_FRONT_RIGHT.high));
        break;

      case STATE_NEGATIVE: // while turning left
        set_led(&LED_FRONT_LEFT, map(CH2.value, -100, 0, LED_FRONT_RIGHT.low, LED_FRONT_LEFT.high));
        set_led(&LED_FRONT_RIGHT, map(CH1.value, -100, 0, LED_FRONT_RIGHT.low, LED_FRONT_LEFT.value));
        break;
    }

    set_led(&LED_REAR_LEFT, map(CH2.value, -100, 0, LED_REAR_LEFT.low, LED_REAR_LEFT.high));
    set_led(&LED_REAR_RIGHT, map(CH2.value, -100, 0, LED_REAR_RIGHT.low, LED_REAR_RIGHT.high));
    return;
  }
}


/* LEDs will always be HIGH in the direction we're currently travelling in,
 * but the opposite end of the car will fade towards the low value.
 */
void process_inverted_single() {
  // going forwards
  if (CH2.state == STATE_POSITIVE) {
    set_led(&LED_FRONT_LEFT, LED_FRONT_LEFT.high);
    set_led(&LED_FRONT_RIGHT, LED_FRONT_RIGHT.high);
    set_led(&LED_REAR_LEFT, map(CH2.value, 0, 100, LED_REAR_LEFT.high, LED_REAR_LEFT.low));
    set_led(&LED_REAR_RIGHT, map(CH2.value, 0, 100, LED_REAR_RIGHT.high, LED_REAR_RIGHT.low));
    return;
  }

  // going nowhere...
  if (CH2.state == STATE_IDLE) {
    set_led(&LED_FRONT_LEFT, LED_FRONT_LEFT.high);
    set_led(&LED_FRONT_RIGHT, LED_FRONT_RIGHT.high);
    set_led(&LED_REAR_LEFT, LED_REAR_LEFT.high);
    set_led(&LED_REAR_RIGHT, LED_REAR_RIGHT.high);
    return;
  }

  // going backwards
  if (CH2.state == STATE_NEGATIVE) {
    set_led(&LED_FRONT_LEFT, map(CH2.value, -100, 0, LED_REAR_LEFT.low, LED_REAR_LEFT.high));
    set_led(&LED_FRONT_RIGHT, map(CH2.value, -100, 0, LED_REAR_RIGHT.low, LED_REAR_RIGHT.high));
    set_led(&LED_REAR_LEFT, LED_REAR_LEFT.high);
    set_led(&LED_REAR_RIGHT, LED_REAR_RIGHT.high);
    return;
  }

  // shouldn't be able to get here
  set_led(&LED_FRONT_LEFT, LED_FRONT_LEFT.high);
  set_led(&LED_FRONT_RIGHT, LED_FRONT_RIGHT.high);
  set_led(&LED_REAR_LEFT, LED_REAR_LEFT.high);
  set_led(&LED_REAR_RIGHT, LED_REAR_RIGHT.high);
}


void process_inverted() {
  if (CH1.available && CH2.available) {
    process_inverted_dual();
    // if (LED_FRONT_LEFT.value < LED_FRONT_LEFT.low) LED_FRONT_LEFT.value = LED_FRONT_LEFT.low;
    // if (LED_FRONT_RIGHT.value < LED_FRONT_RIGHT.low) LED_FRONT_RIGHT.value = LED_FRONT_RIGHT.low;
    // if (LED_REAR_LEFT.value < LED_REAR_LEFT.low) LED_REAR_LEFT.value = LED_REAR_LEFT.low;
    // if (LED_REAR_RIGHT.value < LED_REAR_RIGHT.low) LED_REAR_RIGHT.value = LED_REAR_RIGHT.low;
  } else {
    process_inverted_single();
  }
}


void process_leds() {
  switch (current_mode) {
    case MODE_DYNAMIC:
      process_dynamic();
      break;

    case MODE_INVERTED:
      process_inverted();
      break;

    case MODE_BREATHING:
      process_breathing();
      break;

    case MODE_LOW:
      set_led(&LED_FRONT_LEFT, LED_FRONT_LEFT.low);
      set_led(&LED_FRONT_RIGHT, LED_FRONT_RIGHT.low);
      set_led(&LED_REAR_LEFT, LED_REAR_LEFT.low);
      set_led(&LED_REAR_RIGHT, LED_REAR_RIGHT.low);
      break;

    case MODE_HIGH:
      set_led(&LED_FRONT_LEFT, LED_FRONT_LEFT.high);
      set_led(&LED_FRONT_RIGHT, LED_FRONT_RIGHT.high);
      set_led(&LED_REAR_LEFT, LED_REAR_LEFT.high);
      set_led(&LED_REAR_RIGHT, LED_REAR_RIGHT.high);
      break;

    case MODE_DISABLED:
    default:
      set_led(&LED_FRONT_LEFT, 0);
      set_led(&LED_FRONT_RIGHT, 0);
      set_led(&LED_REAR_LEFT, 0);
      set_led(&LED_REAR_RIGHT, 0);
      break;
  }

  update_led(&LED_FRONT_LEFT);
  update_led(&LED_FRONT_RIGHT);
  update_led(&LED_REAR_LEFT);
  update_led(&LED_REAR_RIGHT);
}


unsigned long blinker_updated = -1;
unsigned long blinker_diff;
void is_unconnected() {
  if (builtin_timer == -1) {
    builtin_timer = millis();
    blinker_updated = millis();

    builtin_value = true;
    digitalWrite(LED_BUILTIN, builtin_value ? HIGH : LOW);
    write_led(&LED_FRONT_LEFT, builtin_value ? LED_FRONT_LEFT.high : LED_FRONT_LEFT.low);
    write_led(&LED_REAR_LEFT, builtin_value ? LED_REAR_LEFT.high : LED_REAR_LEFT.low);
    write_led(&LED_REAR_RIGHT, builtin_value ? LED_REAR_RIGHT.high : LED_REAR_RIGHT.low);
    write_led(&LED_FRONT_RIGHT, builtin_value ? LED_FRONT_RIGHT.high : LED_FRONT_RIGHT.low);
  }

  if ((millis() - builtin_timer) > BLINKER_SPEED) {
    builtin_timer = millis();
    builtin_value = !builtin_value;

    digitalWrite(LED_BUILTIN, builtin_value ? HIGH : LOW);
  }

  if ((millis() - blinker_updated) > 20) {
    blinker_updated = millis();

    blinker_diff = millis() - builtin_timer;
    if (blinker_diff > BLINKER_SPEED) blinker_diff = BLINKER_SPEED;
    if (builtin_value) {
      write_led(&LED_FRONT_LEFT, map(blinker_diff, 0, BLINKER_SPEED, LED_1_HIGH, LED_1_LOW));
      write_led(&LED_REAR_LEFT, map(blinker_diff, 0, BLINKER_SPEED, LED_2_HIGH, LED_2_LOW));
      write_led(&LED_REAR_RIGHT, map(blinker_diff, 0, BLINKER_SPEED, LED_3_HIGH, LED_3_LOW));
      write_led(&LED_FRONT_RIGHT, map(blinker_diff, 0, BLINKER_SPEED, LED_4_HIGH, LED_4_LOW));
    } else {
      write_led(&LED_FRONT_LEFT, map(blinker_diff, 0, BLINKER_SPEED, LED_1_LOW, LED_1_HIGH));
      write_led(&LED_REAR_LEFT, map(blinker_diff, 0, BLINKER_SPEED, LED_2_LOW, LED_2_HIGH));
      write_led(&LED_REAR_RIGHT, map(blinker_diff, 0, BLINKER_SPEED, LED_3_LOW, LED_3_HIGH));
      write_led(&LED_FRONT_RIGHT, map(blinker_diff, 0, BLINKER_SPEED, LED_4_LOW, LED_4_HIGH));
    }
  }
}


void clear_unconnected() {
  builtin_timer = -1;
}


void loop() {
  if (ServoInput.anyAvailable()) {
    clear_unconnected();
    read_values();
    process_switch();
    process_leds();
    delay(20);
  } else {
    is_unconnected();
  }
}

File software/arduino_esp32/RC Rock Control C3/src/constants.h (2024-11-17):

#pragma once
#define PIN_CH1 20
#define PIN_CH2 10
#define PIN_LED_1 3
#define PIN_LED_2 2
#define PIN_LED_3 1
#define PIN_LED_4 0
#define PIN_CFG 7

#define LED_BUILTIN 8
#define PIN_BOOT 9

#define STATE_INVALID 0
#define STATE_IDLE 1
#define STATE_ACTIVE 2
#define STATE_NEGATIVE 2
#define STATE_POSITIVE 3

#define MODE_DISABLED 0
#define MODE_DYNAMIC 1
#define MODE_INVERTED 2
#define MODE_BREATHING 3
#define MODE_LOW 4
#define MODE_HIGH 5
#define MODE_LAST MODE_HIGH

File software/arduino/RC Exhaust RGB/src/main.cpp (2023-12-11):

#include <Arduino.h>
#include "constants.h"
#include "settings.h"

int last_pulse = 0;
long last_value = 0;
long current_value = 0;
bool value_changed = false;

double corrected;
byte num_blanks, blank_start;
byte current_gear = GEAR_NEUTRAL;
byte last_gear = -1;
bool gear_changed = false;
long gauge_value;

unsigned long last_max_value = millis();

uint8_t glow = 0;
uint8_t flicker_cycle = 0;
uint8_t backfire_cycle = BACKFIRE_CYCLES;
unsigned long last_update = millis();
unsigned int change_delta = 150;

/* LEDs are reverse-biased, so the actual value to use with them is at the
 * opposite end of the spectrum (0 is full, 255 is off).
 */
uint8_t adjust_rgb(const uint8_t pin, const uint8_t value) {
  return LED_MAX - value;
  // return pgm_read_byte(&gamma_values[LED_OFF - value]);
}

/* If there's a need to sort out any kind of colour-specific tweaks, this
 * is probably the place to do it.
 */
void set_led(const uint8_t pin, const uint8_t value) {
  switch (pin) {
    default:
      analogWrite(pin, adjust_rgb(pin, value));
      break;
  }
}

int map_input() {
  /* Disable interrupts to increase accuracy */
  noInterrupts();
  last_pulse = pulseIn(PIN_THR, HIGH, 25000);
  interrupts();

  /* Second attempt at reading the value. This may be a mistake of my own doing
   * or something else entirely, but for some reason the second pulse read is
   * always more accurate.
   */
  noInterrupts();
  last_pulse = pulseIn(PIN_THR, HIGH, 25000);
  interrupts();

  if (last_pulse == 0) return 0;
  #ifdef THROTTLE_FUDGE
  /* It appears that we can't really rely on the values from pulseIn as it does
   * some calculation based on how long the chip takes to run through a certain
   * set of loops, this value is wrong for the DigiStump chips that I have. So
   * to get numbers we can work with, we'll have to work our way backwards
   * through the calculation and fudge the numbers a bit.
   * 
   * The way you can tell if this is the problem, it should appear as if the
   * speed going forward caps out early while reverse will appear as neutral
   * beyond a certain value (this is caused by an overflow in the Attiny core).
   */
  corrected = last_pulse + 16;
  corrected = (corrected) / 16.0;
  corrected = (corrected * THROTTLE_FUDGE);
  corrected = corrected - THROTTLE_FUDGE;
  last_pulse = corrected;
  #endif

	if (last_pulse <= THROTTLE_PULSE_MIN) return -100;
	if (last_pulse >= THROTTLE_PULSE_MAX) return 100;
  return map(last_pulse, THROTTLE_PULSE_MIN, THROTTLE_PULSE_MAX, -100, 100);
}

/* This will read the throttle value, but take note that current_value will
 * read as 0 (stick in neutral position) even while a signal is not present
 * such as when it isn't connected to the receiver.
 */
void read_throttle() {
  current_value = map_input();
  if (last_pulse != 0) {
    value_changed = (current_value != last_value);
    last_value = current_value;
  } else {
    value_changed = false;
  }
}

void setup() {
  pinMode(PIN_RGB_R, OUTPUT);
  pinMode(PIN_RGB_G, OUTPUT);
  pinMode(PIN_RGB_B, OUTPUT);
  pinMode(PIN_THR, INPUT);

  for (int i = 0; i < 2; i++) {
    set_led(PIN_RGB_R, LED_OFF);
    set_led(PIN_RGB_G, LED_OFF);
    set_led(PIN_RGB_B, LED_OFF);
    delay(100);
    set_led(PIN_RGB_R, LED_NOTICE);
    set_led(PIN_RGB_G, LED_NOTICE);
    set_led(PIN_RGB_B, LED_NOTICE);
    delay(100);
  }
  set_led(PIN_RGB_R, LED_OFF);
  set_led(PIN_RGB_G, LED_OFF);
  set_led(PIN_RGB_B, LED_OFF);
}

/* While the values we end up with can be considered to be between -100
 * and 100, zero being neutral, we need something slightly less fuzzy to
 * work with. Generally we use the low threshold in both direction as a
 * configurable deadzone, placing the gears to each side of it.
 */
byte get_gear() {
  if (current_value > LOW_THRESHOLD) return GEAR_DRIVE;
  if (current_value < -(LOW_THRESHOLD)) return GEAR_REVERSE;
  return GEAR_NEUTRAL;
}

void analyze() {
  current_gear = get_gear();
  if (last_pulse != 0) {
    gear_changed = (current_gear != last_gear);
    last_gear = current_gear;
  } else {
    gear_changed = false;
  }
  
  gauge_value = current_value;
  if (gauge_value < 0) gauge_value = -gauge_value;
  if (current_gear != GEAR_NEUTRAL) {
    if (gauge_value > HIGH_THRESHOLD) {
      last_max_value = millis();
    }
  }

  if (gear_changed) {
    last_update = millis();
    flicker_cycle = 0;

    /* Start a new backfire sequence if we've returned to neutral with the
     * gauge at the maximum, meaning that we're driving it hard. Ideally,
     * because the logic falls apart somewhere.
     * 
     * @todo Maybe fix this.
     */
    if (current_gear == GEAR_NEUTRAL) {
      if ((millis() - last_max_value) < BACKFIRE_TIMER) {
        backfire_cycle = BACKFIRE_CYCLES;
      }
    }
  } else {
    switch (current_gear) {
      case GEAR_NEUTRAL:
        if (glow > 0) {
          glow--;
        }

        last_update = millis();
        break;

      case GEAR_DRIVE:
      case GEAR_REVERSE:
      default:
        /* Gauge value should a value from 0 to 100, using it as a time
         * difference so that glow accumulates faster under heavy throttle.
         */
        change_delta = 100 - gauge_value;

        if ((millis() - last_update) > change_delta) {
          if (glow < 255) {
            glow++;
          }
          last_update = millis();
        }  
        break;
    }
  }
}

void accelerate() {
  flicker_cycle++;

  switch (flicker_cycle % 16) {
    #ifndef LESS_FLICKER
      case 0:
        set_led(PIN_RGB_R, LED_LOW);
        set_led(PIN_RGB_G, LED_LOW);
        set_led(PIN_RGB_B, LED_OFF);
        break;
    #endif

    case 8:
      set_led(PIN_RGB_R, LED_MAX);
      set_led(PIN_RGB_G, LED_OFF);
      set_led(PIN_RGB_B, LED_OFF);
      break;

    default:
      set_led(PIN_RGB_R, glow);
      set_led(PIN_RGB_G, LED_OFF);
      set_led(PIN_RGB_B, LED_OFF);
      break;
  }
}

void backfire() {
  if (backfire_cycle > 0) {
    switch (flicker_cycle % 32) {
      #ifndef LESS_FLICKER
      case 20:
      case 22:
      case 24:
        set_led(PIN_RGB_R, LED_LOW);
        set_led(PIN_RGB_G, LED_LOW);
        set_led(PIN_RGB_B, LED_LOW);
        break;
      #endif

      case 28:
      case 29:
        set_led(PIN_RGB_R, LED_MAX);
        set_led(PIN_RGB_G, LED_OFF);
        set_led(PIN_RGB_B, LED_OFF);
        break;

      default:
        set_led(PIN_RGB_R, glow);
        set_led(PIN_RGB_G, LED_OFF);
        set_led(PIN_RGB_B, LED_OFF);
        break;
    }

    backfire_cycle--;
  }
  
  flicker_cycle++;
}
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

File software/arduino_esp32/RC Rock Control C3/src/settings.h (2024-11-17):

#pragma once
/* These values need to be adjusted to the values used by your transmitter and
 * receiver combination. Failiure to do so may cause the lighting system to
 * trigger prematurely or not at all.
 */
#define CH1_PULSE_MIN 1000
#define CH1_PULSE_MAX 2000
#define CH2_PULSE_MIN 1000
#define CH2_PULSE_MAX 2000

#define LED_1_LOW 8
#define LED_1_HIGH 255
#define LED_1_DEFAULT LED_1_LOW
#define LED_2_LOW LED_1_LOW
#define LED_2_HIGH LED_1_HIGH
#define LED_2_DEFAULT LED_2_LOW
#define LED_3_LOW LED_1_LOW
#define LED_3_HIGH LED_1_HIGH
#define LED_3_DEFAULT LED_3_LOW
#define LED_4_LOW LED_1_LOW
#define LED_4_HIGH LED_1_HIGH
#define LED_4_DEFAULT LED_4_LOW

#define LED_STEPS 10
#define BLINKER_SPEED 375
#define BREATHING_SPEED 2000
#define DEFAULT_MODE MODE_DYNAMIC

/* The hardware can combine two outputs in order to have a difference in
 * brightness, allowing a light to operate in three modes: off/low/high.
 * The code has therefore been implemented with the same modes, but placed
 * at specific thresholds in relation to controller input. This mostly applies
 * to channel2.
 */
#define LOW_THRESHOLD 10
#define HIGH_THRESHOLD 80

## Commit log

2023-08-10 Output schematic
    [Ports.sch, RC Light System Output.kicad_pcb, RC Light System Output.sch]
2023-08-11 Map footprints and add transistor pulldowns
    [Ports.sch, RC Light System Output.sch]
2023-08-12 Big boy output layout
    [RC Light System Output.kicad_pcb, RC Light System Output.sch]
2023-08-19 Control module schematic
    [RC Light System.kicad_pcb, RC Light System.sch]
2023-08-24 First layout done
    [Ports.sch, RC Light System Output.kicad_pcb, RC Light System.kicad_pcb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]
2023-08-31 Exhaust module
    [RC Exhaust System.kicad_pcb, RC Exhaust System.sch, RC Light System Output.kicad_pcb]
2023-09-30 Added voltage dividers
    [RC Exhaust System RGB.kicad_pcb, RC Exhaust System RGB.sch, RC Light System.kicad_pcb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]
2023-11-19 Printing THR
2023-11-26 Works some of the time, readings are glitched in some way
    [main.cpp]
2023-11-27 Changed to a library, appears to function
    [RC Light System.kicad_pcb]
2023-11-27 Doesn't park when we're standing still, but actively steering
    [main.cpp, settings.h]
2023-11-28 Added calibration sketch
2023-12-01 Exhaust as a digispark module
    [RC Exhaust Digispark-B_Cu.gbl, RC Exhaust Digispark-B_Mask.gbs, RC Exhaust Digispark-B_Paste.gbp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]
2023-12-01 Simplified power to use 5/6v
    [RC Light System.kicad_pcb, RC Light System.sch]
2023-12-05 Digispark dashboard sketch
    [RC Exhaust Digispark.kicad_pcb, RC Exhaust Digispark.sch]
2023-12-07 Archive some designs as I probably won't keep working on them
    [RC Exhaust System RGB-B_Cu.gbl, RC Exhaust System RGB-B_Mask.gbs, RC Exhaust System RGB-B_Paste.gbp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]
2023-12-07 Dashboard module for Digispark
    [RC Dashboard Digispark.kicad_pcb, RC Dashboard Digispark.sch]
2023-12-10 Add code to limit throttle bar display when in reverse
    [main.cpp, settings.h]
2023-12-10 Add alternate gear styling
2024-02-05 Mini, though actually kind of huge, output module
    [Ports.sch, RC Dashboard Digispark.kicad_pcb, RC Light System Output Mini.kicad_pcb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]
2024-03-26 Small build tweaks to sizing and text
    [RC Dashboard Digispark.kicad_pcb, RC Dashboard Digispark.sch]
2024-06-23 Small exhaust tweaks to better fit Digistump into computers
    [RC Exhaust Digispark-B_Cu.gbl, RC Exhaust Digispark-B_Mask.gbs, RC Exhaust Digispark-B_Paste.gbp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]
2024-06-25 Slightly tweak layout
    [RC Exhaust Digispark.kicad_pcb]
2024-07-24 Trying out ESP32 C3
2024-07-25 Change to ServoInput and move project
2024-07-26 SuperMini board
    [RC Dashboard SuperMini.kicad_pcb, RC Dashboard SuperMini.kicad_sch, RC Dashboard SuperMini.sch]
2024-08-02 Small build tweaks
    [RC Dashboard SuperMini.kicad_pcb, RC Dashboard SuperMini.kicad_sch]
2024-08-02 Adding a delay fixes u8g2 startup issue???
    [constants.h, main.cpp]
2024-08-03 Preparing for the next thing
    [RC Dashboard SuperMini.kicad_pcb, RC Dashboard SuperMini.kicad_sch]
2024-08-04 SuperMini2, same as the old one except bigger and has two LED channels
    [RC Dashboard SuperMini2.kicad_pcb, RC Dashboard SuperMini2.kicad_sch, RC Dashboard SuperMini2.sch]
2024-11-11 Add a couple of LED-channels
2024-11-12 Blink LEDs
2024-11-13 SCX10.3 Rock lights
    [RC SCX10.3 Rock Control.kicad_pcb, RC SCX10.3 Rock Control.kicad_sch, RC SCX10.3 Rock Control.sch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]
2024-11-17 LEDs make more sense
2024-11-17 Slight build tweaks
    [RC Dashboard SuperMini2.kicad_pcb]
2024-11-17 Missing track
    [RC Dashboard SuperMini2.kicad_pcb]
2024-11-17 Added steering to inverted mode
    [main.cpp, settings.h]
2024-11-18 Dynamic value linked to other LED, not channel
2024-11-18 Make it easier to fit diode the right way around
    [RC SCX10.3 Rock Light.kicad_pcb]

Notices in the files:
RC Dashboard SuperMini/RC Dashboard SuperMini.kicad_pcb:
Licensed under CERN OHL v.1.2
